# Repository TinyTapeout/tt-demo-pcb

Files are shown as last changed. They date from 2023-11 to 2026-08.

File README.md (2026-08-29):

# Tiny Tapeout Demo Board

Demo board for Tiny Tapeout ASICs

Demoboard PCB

These demonstration PCBs allow you to interact with [Tiny Tapeout](https://tinytapeout.com/) projects in 3 ways:

  * directly, using the input DIP switches and 7-segment display;
  * via breadboard or extension boards through PMODs; or
  * by interacting through the on-board RP2

Demoboard PCB

In addition, since TT06, it is possible to create analog and mixed signal designs.  These signals are now available on a 100mil header directly on the demoboard

Breakout Board Analog IO

## Pinout Overview

Demoboard Pinout

### Previous Demoboard Versions

The details above are for the latest version of the demoboard.  To access leaflets and schematics for prior versions, see [here, in the historic documentation](doc/historic/README.md)

## Schematic and Function

The full schematic is available as a [PDF](doc/tt-etr-dbv3.pdf) but the gist of it is:

Demoboard schematic

The RP2350 is responsible for selecting projects, by controlling the project MUX that's on the ASIC and, under most circumstances, providing the clock for the projects. It may, thereafter, interact with the design via it's connections to the input, output and bidirectional pins.

Another option is to use the various PMOD and pin headers to tie external circuitry to the design.  PMODs are provided in two varieties: straightforward I/O (where one PMOD is dedicated to each of in/out/bidir pins) and "standard" PMODs, that are mapped (mostly) according to specs to allow for SPI, I2C and UART extension boards to be plugged in (this assumes the project has been designed with this in mind, with I/O tasked accordingly). 

## PMODs

In addition with interfacing directly with projects via the RP2, extensions and interaction with the ASIC is possible through two sets of [PMODs](https://digilent.com/reference/_media/reference/pmod/pmod-interface-specification-1_2_0.pdf) on the demo boards.

The three on the bottom provide access to all the project I/O in a logical fashion, with inputs, bidirectional pins and outputs available on their own distinct headers.

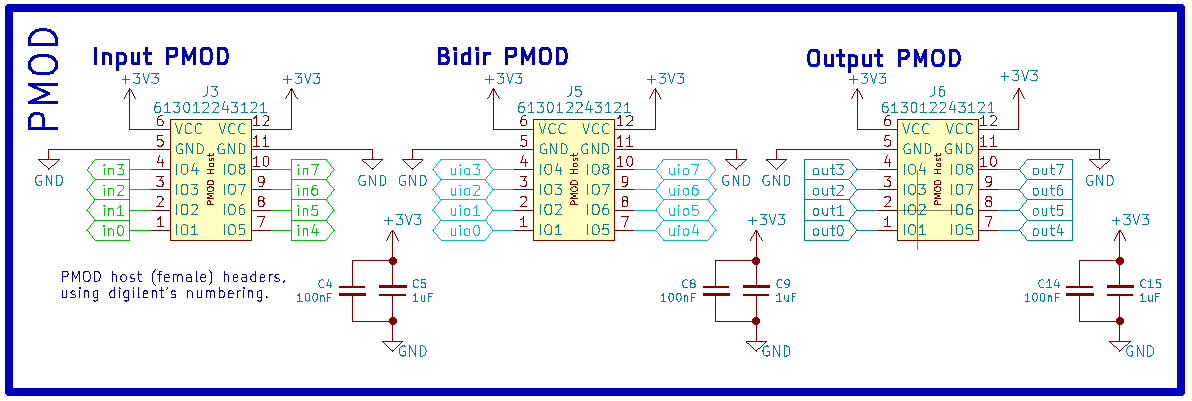
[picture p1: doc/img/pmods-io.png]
IO PMODs


This is nice and orderly and gives you access to all the pins, but extension boards will often need to span at least two, and sometimes three, distinct headers.

For interfacing peripheral modules, an interposer board was created (TODO: display and link) to provide more standard mixes of input and output on single PMODs.

## RP2 Pinout

| TT Pin | RP2 Pin | I2C | SPI | UART |
| --- | --- | --- | --- | --- |
| reset | GPIO14 | | | |
| clock | GPIO16 | | | |
| ui_in[0]  | GPIO17 | | SPI0.cs  | |
| ui_in[1]  | GPIO18 | | SPI0.sck | |
| ui_in[2]  | GPIO19 | | SPI0.tx  | |
| ui_in[3]  | GPIO20 | | | UART1.tx |
| ui_in[4]  | GPIO21 | | SPI0.cs  | |
| ui_in[5]  | GPIO22 | | SPI0.sck | |
| ui_in[6]  | GPIO23 | | SPI0.tx  | UART1.rts|
| ui_in[7]  | GPIO24 | | | |
| uio[0] | GPIO25 | I2C0.scl | SPI1.cs  | UART1.rx |
| uio[1] | GPIO26 | I2C1.sda | SPI1.sck | UART1.cts|
| uio[2] | GPIO27 | I2C1.scl | SPI1.tx  | UART0.rts|
| uio[3] | GPIO28 | I2C0.sda | SPI1.rx  | UART0.tx |
| uio[4] | GPIO29 | I2C0.scl | SPI1.cs  | UART0.rx |
| uio[5] | GPIO30 | I2C1.sda | SPI1.sck | UART0.cts|
| uio[6] | GPIO31 | I2C1.scl | SPI1.tx  | UART0.rts|
| uio[7] | GPIO32 | | | |
| uo_out[0] | GPIO33 | | | UART0.rx |
| uo_out[1] | GPIO34 | | | UART0.cts|
| uo_out[2] | GPIO35 | | | |
| uo_out[3] | GPIO36 | | SPI0.rx  | |
| uo_out[4] | GPIO37 | | | UART1.rx |
| uo_out[5] | GPIO38 | | | UART1.cts|
| uo_out[6] | GPIO39 | | | |
| uo_out[7] | GPIO40 | | SPI0.rx  | |

## Removing the ASIC breakout board

With the [Hirose DF12 Series](https://www.hirose.com/product/series/DF12) connectors now in use, removing breakouts from demoboards should be much more straightforward:

* Insert a finger on opposite diagonals (top left, bottom right)
* Gently pry upwards until the breakout pops off.

There are markings indicating where the actually connectors are placed, on the underside, on the breakouts.

## License

* The PCB is licensed under the [Apache2 License](LICENSE)
* The documentation is licensed under the [CC0](https://creativecommons.org/publicdomain/zero/1.0/)
* OSHWA registration [CA000047](https://certification.oshwa.org/ca000047.html)

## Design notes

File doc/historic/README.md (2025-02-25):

# Schematics for prior demoboard versions

Though this schematic and layout data is all preserved in the commit history, for ease of reference the major milestones are accessible here, in reverse chronological order.

These should be the revisions actually sent to production for distribution.  The PDF includes the full schematic and the preview gives access to the most important information, as the RP2040 support sheet basically doesn't change.

## TT07

With the TT07 demoboard, signal naming was uniformized (using *ui_in*, *uo_out*).

TT07 leaflet

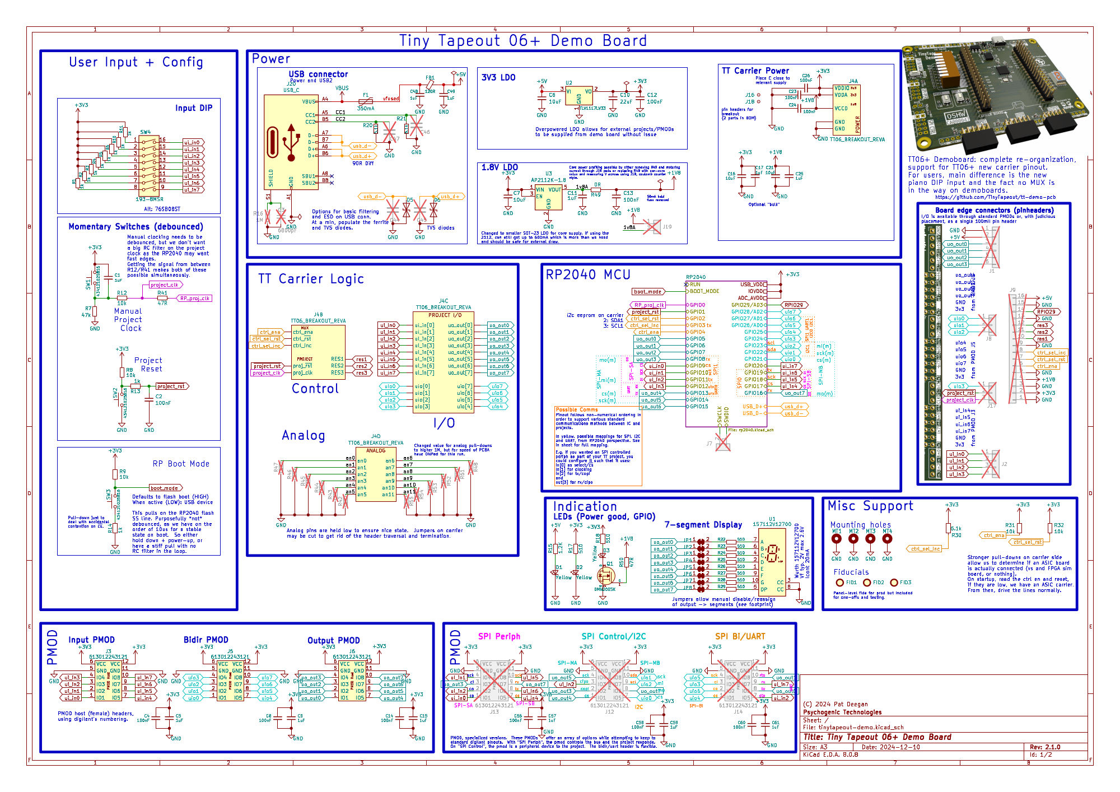
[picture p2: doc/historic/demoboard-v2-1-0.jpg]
TT07 schematic


[Version 2.1.0 schematic PDF](demoboard-v2-1-0.pdf)

Commit a799acb3886b682b0f86c2f4d6155c08b5c505de from Wed Dec 11, 2024

## TT06

With TT06, the discreet MUX was dropped (along with Caravel support), the new much more comfortable piano switches were introduced for the input port.  The carrier format changed to break compatibility with prior boards, because of a new pinout and analog pin support.

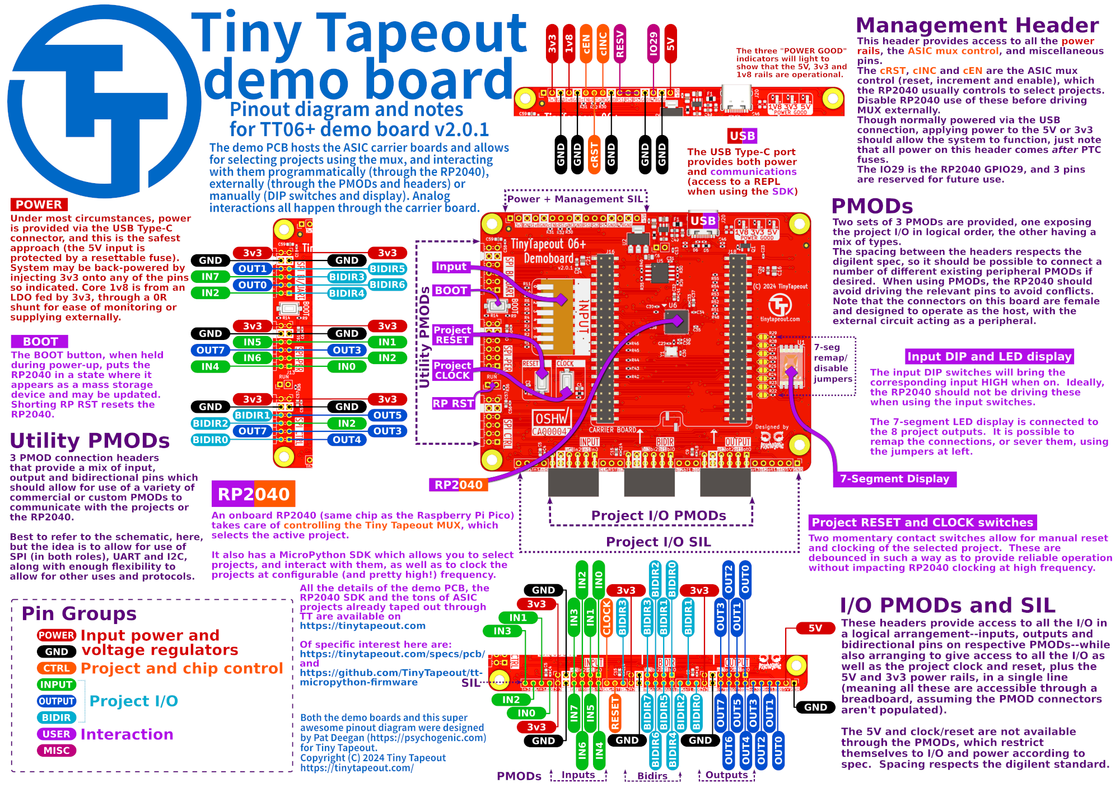
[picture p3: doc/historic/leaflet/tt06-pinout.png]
TT06 leaflet


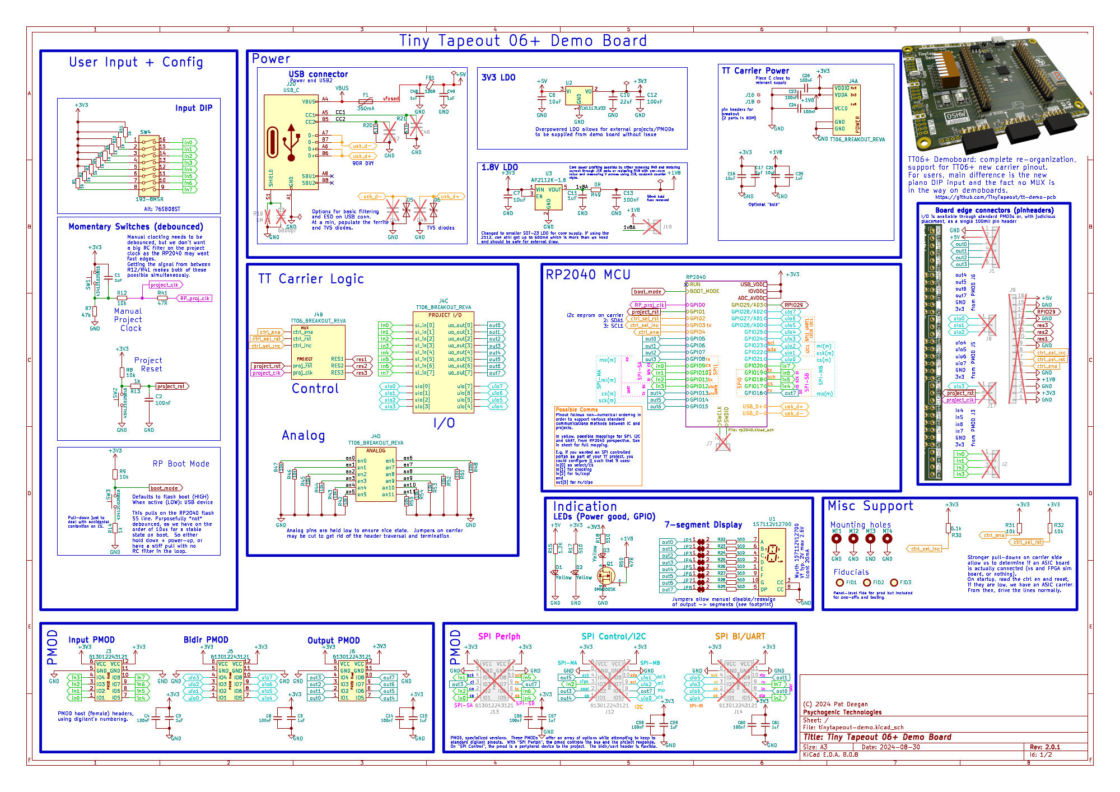
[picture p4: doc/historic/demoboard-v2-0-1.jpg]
TT06 schematic


[Version 2.0.1 schematic PDF](demoboard-v2-0-1.pdf)

Commit 292760e1f727d805be471b7700232c9482b70ae3 from Thu Oct 10, 2024

## TT05

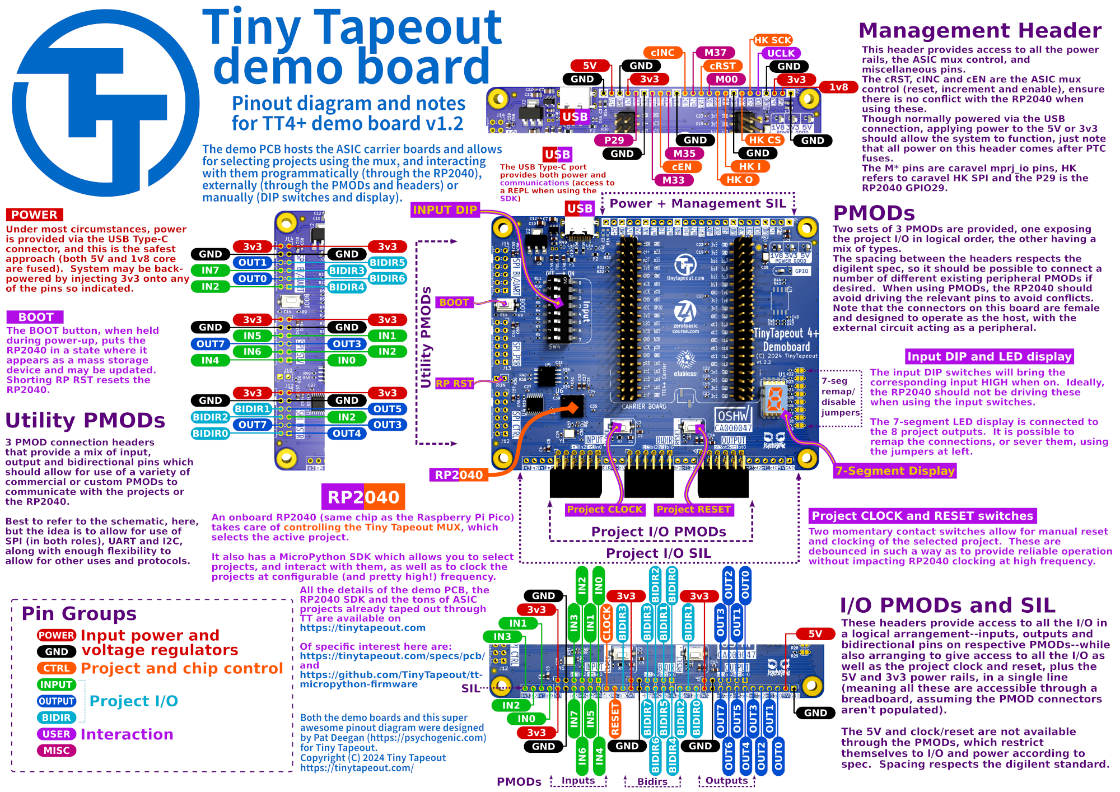
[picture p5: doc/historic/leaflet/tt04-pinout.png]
TT04/TT05 leaflet


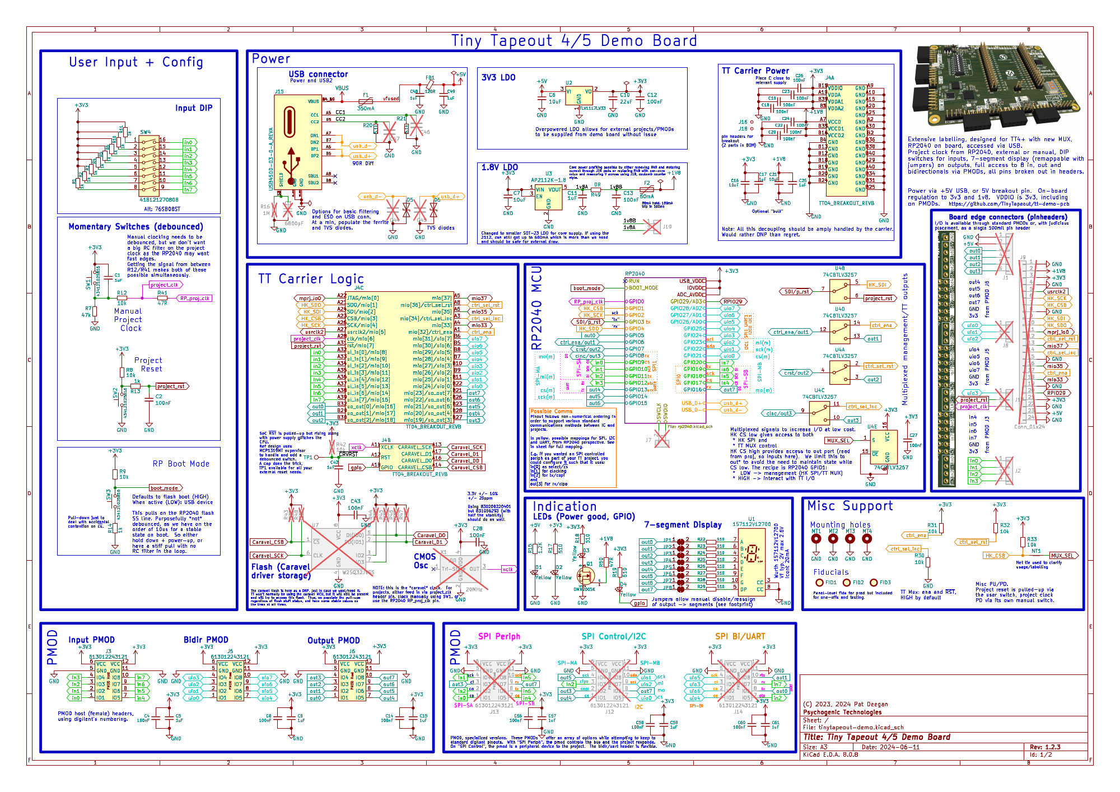
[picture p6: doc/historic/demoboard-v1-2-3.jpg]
TT05 schematic


[Version 1.2.3 schematic PDF](demoboard-v1-2-3.pdf)

Commit a88cbc08bdef564b16dc113f4489af65ff2ee86b from Tue Jun 11, 2024

## TT04

The TT04 demoboard introduced the RP2040, to handle selecting the projects through the ASIC project MUX.  TT04 boards also used a discreet multiplexer in order to provide enough pinnage to do all the things and have access to the caravel HK SPI safety net.

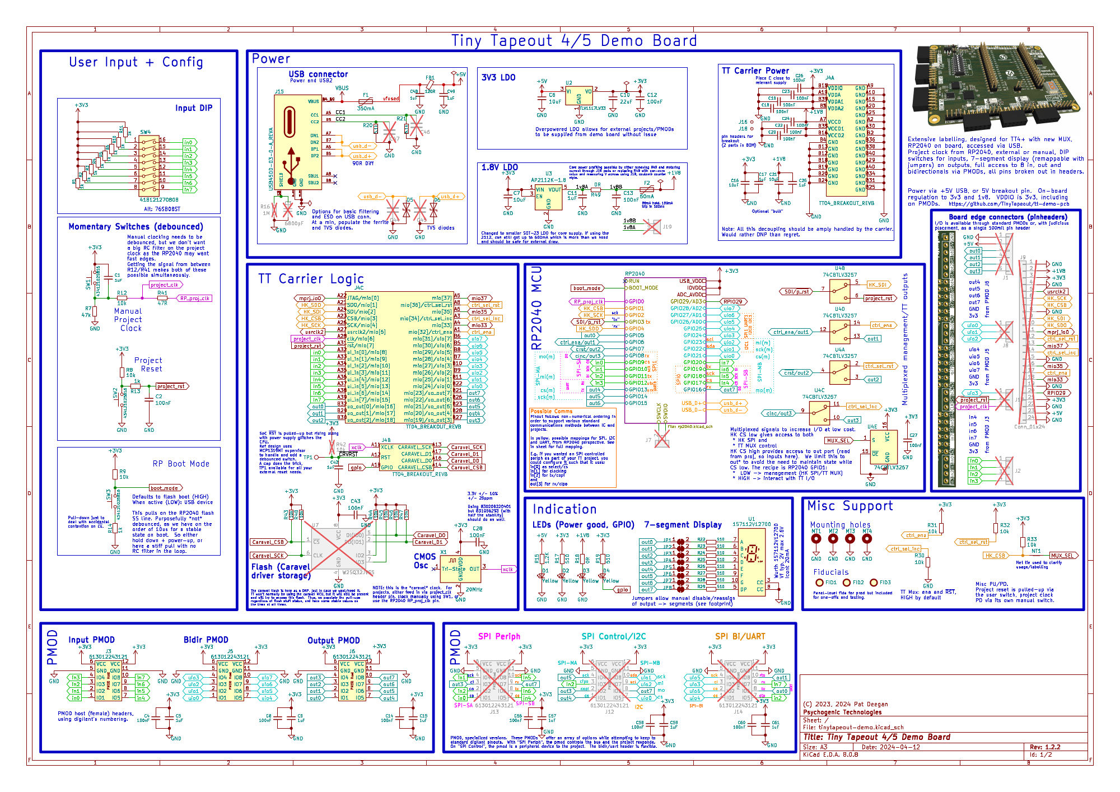
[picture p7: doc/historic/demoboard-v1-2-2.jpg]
TT04 schematic


[Version 1.2.2 schematic PDF](demoboard-v1-2-2.pdf)

Commit cfdd80d7b79a667883998caccc05ebfad5d1b985 from Fri Apr 26, 2024

## TT02/TT03

Original demoboard used with TT02 and TT03.

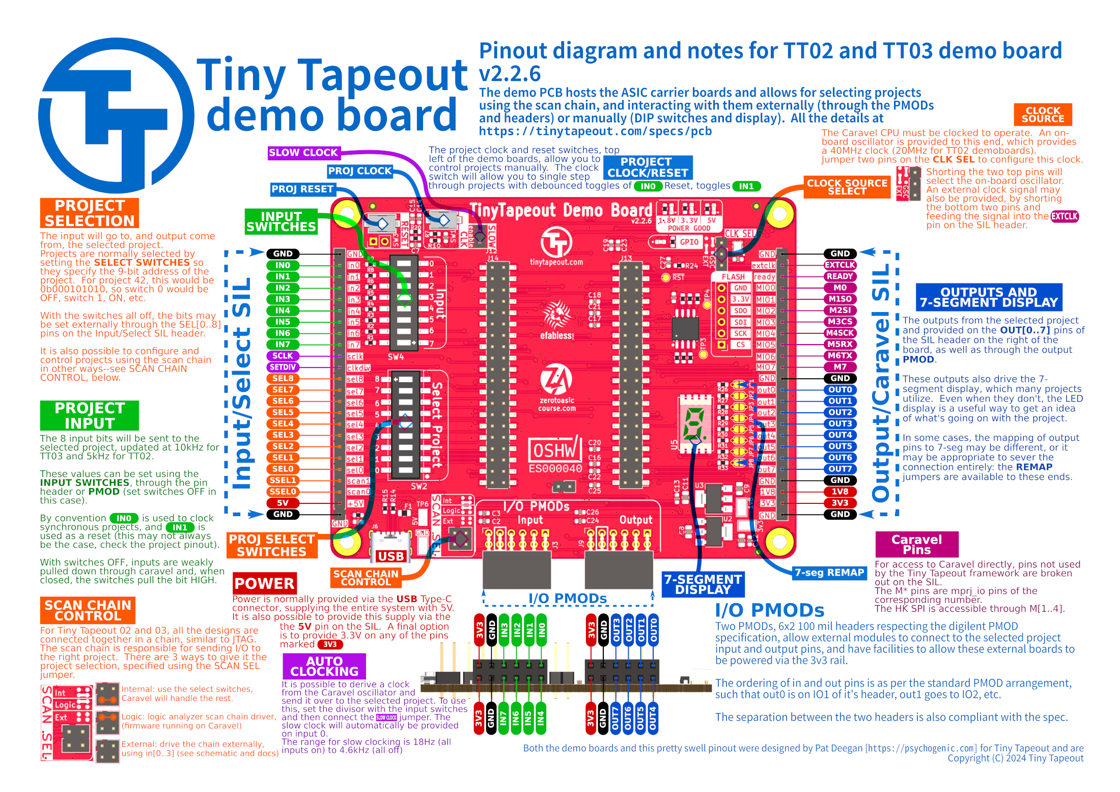
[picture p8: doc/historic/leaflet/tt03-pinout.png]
TT03 leaflet


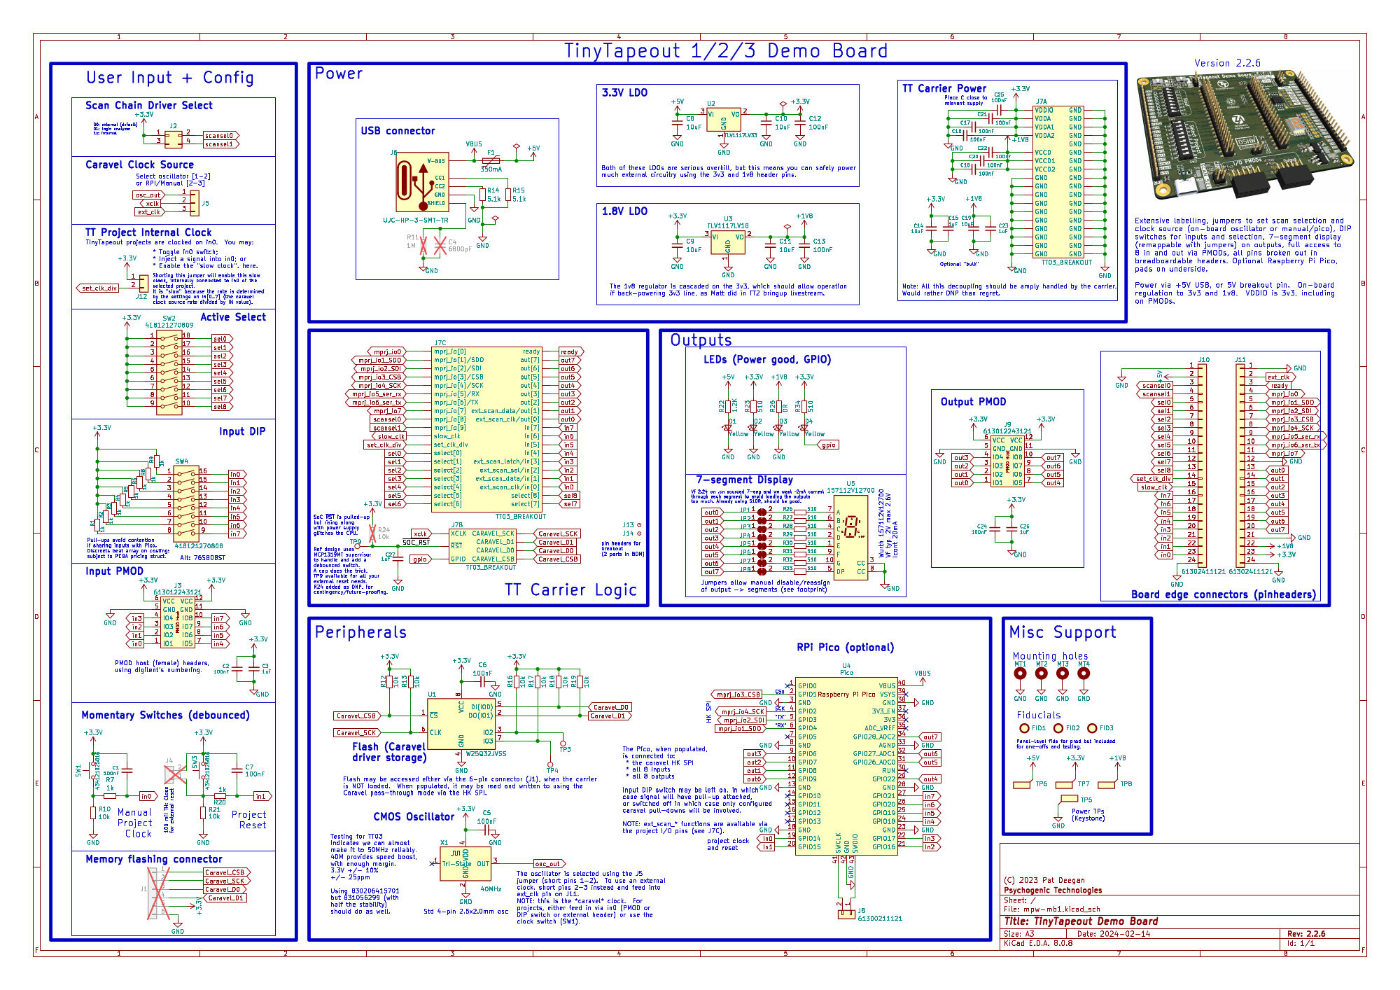
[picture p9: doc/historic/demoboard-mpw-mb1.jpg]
TT03 schematic


[TT03 demoboard schematic PDF](demoboard-mpw-mb1.pdf)

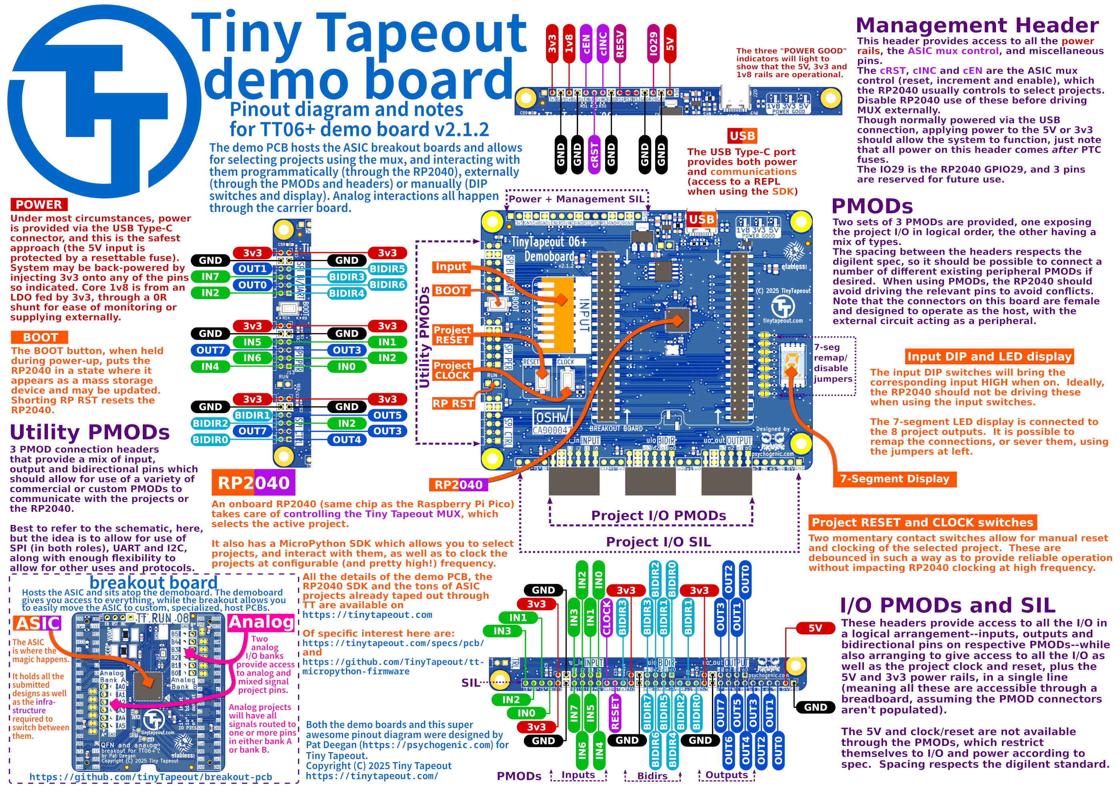
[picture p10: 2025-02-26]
doc/img/tt08-demoboard-pinout.jpg

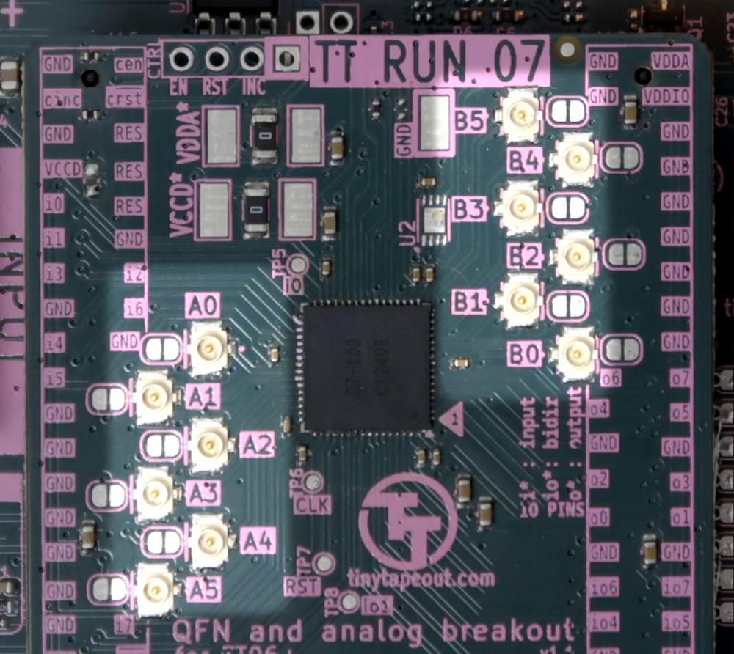
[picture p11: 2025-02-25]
doc/img/tt07-analogio.jpg

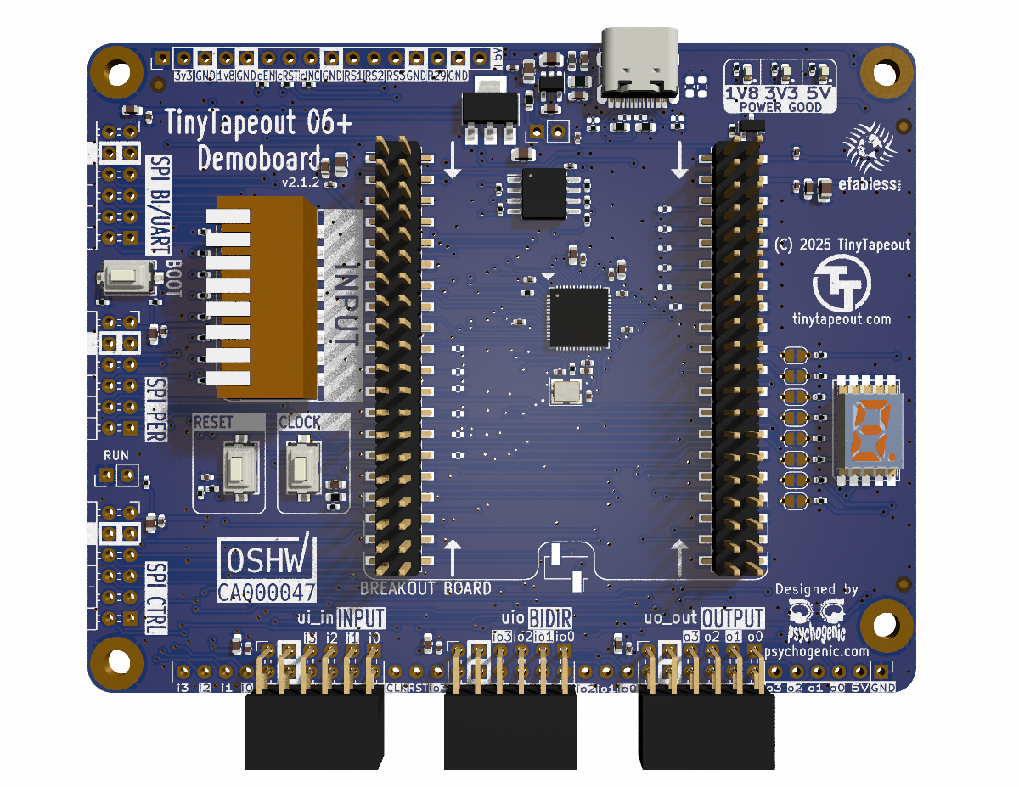
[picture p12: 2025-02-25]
doc/img/tt07-demoboard-render.jpg

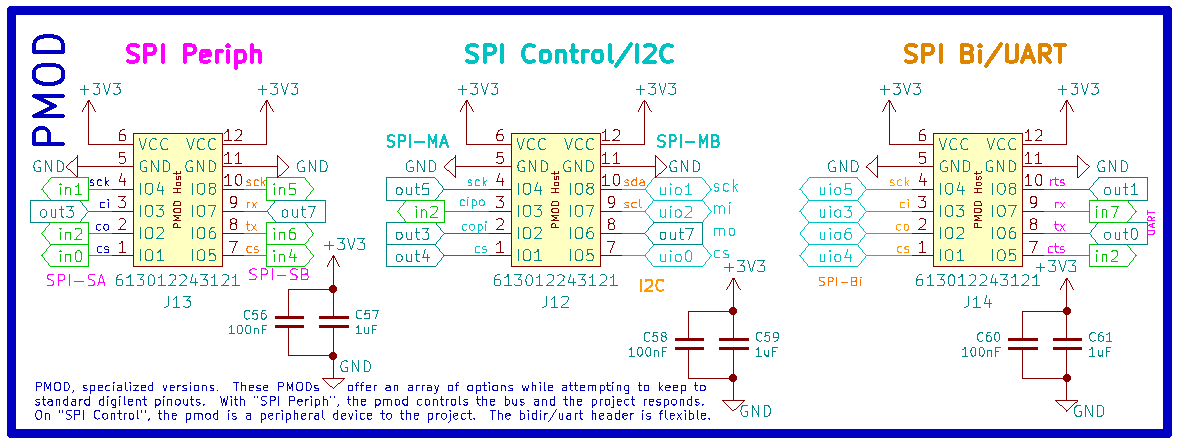
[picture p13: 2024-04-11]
doc/img/pmods-mixed.png

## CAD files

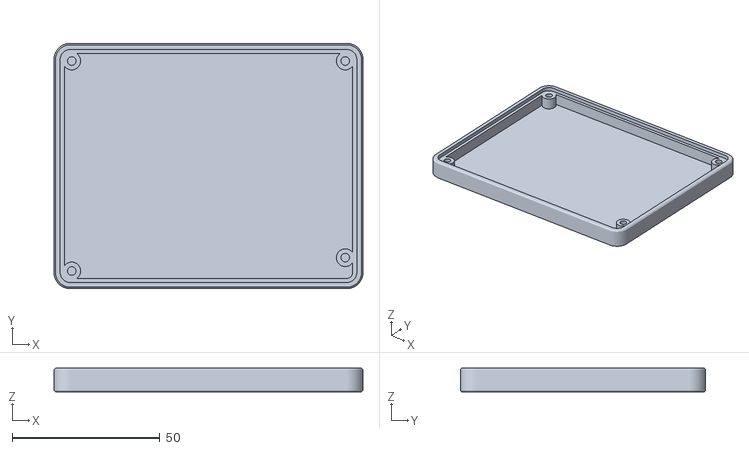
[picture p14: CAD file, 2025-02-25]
case/tt06_demo_base_m3_direct.stl
104.5 x 83.0 x 8.00

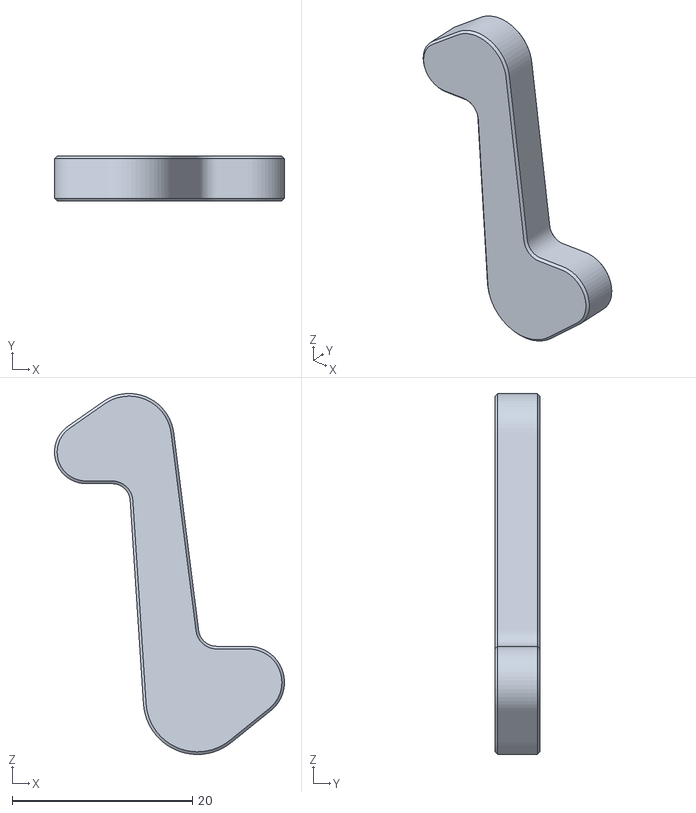
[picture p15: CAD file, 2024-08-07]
pcb_extractor.stl
25.5 x 5.00 x 40.0

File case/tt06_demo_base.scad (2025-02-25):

/* 
 * Base for Tiny Tapeout 06+ Demoboard
 *
 * Design: hxr.social/@thomasflummer
 *
 * License: CC-BY-SA
 *
 */

/*
 * Variables for Customizer
 * ==================================================================
 *
 */

// select type of mounting hardware
Screw_Type = "M2 with insert"; // [M3 direct, M2 with insert]

//-----------------
/* [AdditionalSettings] */ 

// total height (in mm)
Height = 8;

module pcb_base(width, length, pcb_thickness, corner_radius, height, mounting_hole_diameter)
{
    difference()
    {
        union()
        {
            hull()
            {
                for(x = [-1, 1])
                {
                    for(y = [-1, 1])
                    {
                        translate([x*(width/2 - corner_radius), y*(length/2 - corner_radius), height/2])
                            cylinder(r = corner_radius + 2, h = height, center = true, $fn = 150);
                    }
                }

                for(x = [-1, 1])
                {
                    for(y = [-1, 1])
                    {
                        translate([x*(width/2 - corner_radius), y*(length/2 - corner_radius), height/2])
                            cylinder(r = corner_radius + 2 + 0.5, h = height-1, center = true, $fn = 150);
                    }
                }
            }        
        }
        union()
        {
            // PCB cutout
            hull()
            {
                for(x = [-1, 1])
                {
                    for(y = [-1, 1])
                    {
                        translate([x*(width/2 - corner_radius), y*(length/2 - corner_radius), height - pcb_thickness/2])
                            cylinder(r = corner_radius + 0.4, h = pcb_thickness + 0.01, center = true, $fn = 150);
                    }
                }
            }

            // space for PTH pins and rubber feet
            hull()
            {
                for(x = [-1, 1])
                {
                    for(y = [-1, 1])
                    {
                        translate([x*(width/2 - corner_radius), y*(length/2 - corner_radius), height/2 + 1.5])
                            cylinder(r = corner_radius - 1, h = height, center = true, $fn = 150);
                    }
                }
            }
        }
    }
    // studs for screws/inserts
    
    for(x = [-1, 1])
    {
        for(y = [-1, 1])
        {
            if(x == 1 && y == -1)
            {
                difference()
                {
                    translate([x*(width/2 - 3.5), y*(length/2 - 8), (height - pcb_thickness)/2])
                        cylinder(d = 6, h = height - pcb_thickness, center = true, $fn = 150);

                    translate([x*(width/2 - 3.5), y*(length/2 - 8), (height - pcb_thickness)/2])
                        cylinder(d = mounting_hole_diameter, h = height - pcb_thickness + 0.01, center = true, $fn = 150);
                }
            }
            else
            {
                difference()
                {
                    translate([x*(width/2 - 3.5), y*(length/2 - 3.5), (height - pcb_thickness)/2])
                        cylinder(d = 6, h = height - pcb_thickness, center = true, $fn = 150);

                    translate([x*(width/2 - 3.5), y*(length/2 - 3.5), (height - pcb_thickness)/2])
                        cylinder(d = mounting_hole_diameter, h = height - pcb_thickness + 0.01, center = true, $fn = 150);
                }
            }
        }
    }

    
}


if(Screw_Type == "M2 with insert")
{
    pcb_base(99.5, 78, 1.6, 3.0, Height, 3.3);
}

if(Screw_Type == "M3 direct")
{
    pcb_base(99.5, 78, 1.6, 3.0, Height, 2.9);
}

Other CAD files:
case/tt06_demo_base_m2_insert.stl

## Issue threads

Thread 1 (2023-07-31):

Proposed RP2040 pinout

MichaelBell, 2023-07-31:
It would be good to define which RP2040 IOs were connected to which TT user project IOs before TT04 submissions close, so that TT04 projects can know which pins to interface with RP2040 peripherals on (e.g. SPI, UART, I2C and to a lesser extent, PIO).

My proposal for the pinout would be:
```
0   TT <- RP        Input 0
1   TT <- RP        Input 1
2   TT <- RP        Input 2
3   TT <- RP        Input 3
4   TT <- RP        Input 4
5   TT <- RP        Input 5
6   TT <- RP        Input 6
7   TT <- RP        Input 7
8   TT <-> RP       Bidi 0
9   TT <-> RP       Bidi 1
10  TT <-> RP       Bidi 2
11  TT <-> RP       Bidi 3
12  TT <-> RP       Bidi 4
13  TT <-> RP       Bidi 5
14  TT <-> RP       Bidi 6
15  TT <-> RP       Bidi 7
16  TT  -> RP       Output 0
17  TT  -> RP       Output 1
18  TT  -> RP       Output 2
19  TT  -> RP       Output 3
20  TT  -> RP       Output 4
21  TT  -> RP       Output 5
22  TT  -> RP       Output 6
23  TT  -> RP       Output 7
24  Clock Output    CLK
25  Reset           RST_N
26  Controller      SEL_RST_N
27  Controller      SEL_INC
28  Controller      ENA
29  Other           LED
```

Considerations:
- For PIO, useful to be able to use contiguous blocks of pins on RP2040, so arrange the user project IOs contiguously in some order, and have the bidi IOs between the fixed direction IOs so you have the possibility of 16 contiguous inputs or outputs.
- For SPI, SPI0 is available on GPIOs 0-7, 16-23.  SPI1 is available on GPIOs 8-15, 24-29 so with this ordering both can be used (SPI0 through the fixed direction IOs, SPI1 through the bidirectional IOs).
- The UART and I2C repeat in blocks of 8 and 4 respectively, so aligning with those boundaries is sensible
- GPIOs 26-29 should not have voltage applied when the RP2040 is unpowered.  If the board has an option not to power the RP2040 these could be protected with diodes and any added delay/switching frequency concerns should not matter as those signals are not connected to the user project.

urish, 2023-10-13:
Closing as this was discussed on discord

Closed 2023-10-13.

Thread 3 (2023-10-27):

Manual clock 1-step function RC network design area review request

dlmiles, 2023-10-27:
Please review the use of R7/R12/C1 around the manual clock 1-step function.

The concern is in relation to the impact of RC circuit on the signal integrity of the `project_clk` line which is an important aspect to many projects.  Especially as the clock rate is increased through the MHz, towards 50MHz planned max RP2040 and 66MHz the documented max sky130 IO input rate (which maybe should be the PCB design limit, if someone attaches their own clock source while the RP2040 pin is tri-state/HiZ).

In particular it would be ideal validate and measure (possibly with a breadboard setup) how the signal changes at a variety of clock frequencies.  Also the shape of the signal from the button use.

Maybe a reduction of C1 (100nF) to a smaller value turns out to meet requirements ?

Other thoughts in the area:
 * consideration to using GPIO29 (if unused) to connect the clock 1-step switch to this GPIO only, make project_clk driven only by the RP2040 firmware and the removal of any extra capacitance on the project_clk net.  This might have other benefits, a button able to communicate with RP2040 firmware directly opens up other project possibilities?
 * if GPIO29 is possible, potential to leave unpopulated option in PCB design to `relink` manual clock switch back to project_clk (with the customer using a 1x2 header pin + jumper) where the track near R12 was disconnected.
 * is an RC debounce approach enough to provide intended project reliability to students for edge triggered flopflops, some people might consider a schmitt-trigger to provide output to project_clk line from a switch+RC to be the minimum approach

Related discord discussion area links:
https://discord.com/channels/1009193568256135208/1009395924017086475/1167335321365651496
https://discord.com/channels/1009193568256135208/1011201396659474432/1167393079456714783

mattvenn, 2024-03-01:
resolved

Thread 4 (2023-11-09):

caravel reset missing?

mattvenn, 2023-11-09:
I see project reset and project select reset, but not caravel reset. This needs properly taking care of or we will have the same issue for the v2.2.3 tt123 demo boards.

Closed 2024-03-01.

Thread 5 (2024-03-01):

minor fixes

mattvenn, 2024-03-01:
fix copyright on pdf schematic

add license to repo

typo: periphas -> "periph as" on the pdf schematic

readme:

TinyTapeout -> Tiny Tapeout (as per branding guideline on the www)

Add ref to license.

follow oshwa guidelines for SPI port names https://www.oshwa.org/a-resolution-to-redefine-spi-signal-names/

Closed 2024-06-11.

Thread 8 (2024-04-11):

Remove reliance on IO pull-downs

psychogenic, 2024-04-11:
We have, to date, been relying on pull-downs from Caravel.  This won't be possible for TT06 so, assuming we keep the DIP switches on the input, need to organize things differently.

Closed 2025-02-27.

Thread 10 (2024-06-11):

fix 1.8v power led brightness

mattvenn, 2024-06-11:
use a mosfet to drive the led

psychogenic, 2024-06-11:
Done, added a FET and feeding from 3v3.  Series term on gate using value we already have on the board.  Have a range of options on the specific nfet, set the LCSC number to C2891732 (basically an si2302 dirt cheap type deal).
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

Closed 2024-06-11.

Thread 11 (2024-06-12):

current measure header and 1.8 override

mattvenn, 2024-06-12:
The current method of measuring core current is to remove resistor and place a header. I would like the header to be replaced with a standard 2.54 mm pitch.

Also I would like an easy way to provide 1.8 from another source. Perhaps adding an additional gnd hole so that once the resistor is removed a 3 pin header can be placed ?

psychogenic, 2024-06-13:
Ok, replaced header with 100mil version and moved things around (blue arrow).  If you want to power with your own 1v8, remove that same R49 (blue slash) and power through headers indicated in red.  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

mattvenn, 2024-06-13:
Thanks!

Closed 2024-06-13.

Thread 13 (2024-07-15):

removing carrier board with the top header soldered is hard

mattvenn, 2024-07-15:
can't get my levers in there when the top header is soldered (the one next to usb)
if the carrier board was moved to be more central in the demo board, it would be easier to remove it by using levers

mattvenn, 2024-12-11:
with the latest configuration of components it's even harder to get the levers in

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

psychogenic, 2024-12-11:
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
The arrows are meant to indicate where to stick in your level sticks.

mattvenn, 2024-12-11:
I'm trying to say that it needs levering from the top side as well,
otherwise the pins still get bend

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

--
Matthew Venn
 Making chip design more accessible
https://www.linkedin.com/in/matt-venn/
<https://www.linkedin.com/in/matt-venn/>

psychogenic, 2024-12-11:
I have to 3D print some of your thingies, I'd thought you could inch along but they must be too short.

mattvenn, 2024-12-11:
I can get them under, but then they normally are pushing against a component instead of the board. Maybe this is actually fine, I'm just worried about popping off a component or cracking a cap

psychogenic, 2024-12-11:
It's not ideal.  Best thing might be to make the carriers a bit wider so you have a lip to use from the outside.

Closed 2025-02-27.

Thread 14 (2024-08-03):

1v8 and 3v3 on the top SIL are too easy to short if you are not careful

urish, 2024-08-03:
All it takes is one alligator clip slipping a bit and poof!

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

Let's separate them with a GND pin, to reduce the chance of other people repeating my mistake...

Closed 2025-02-27.

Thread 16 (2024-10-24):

Disable RP2040 microcontroller

InputBlackBoxOutput, 2024-10-24:
I cannot find a way to disable RP2040 to use only the PMOD connectors with the clk and reset buttons on the board

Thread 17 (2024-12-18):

efabless logo is missing on the devkits

mattvenn, 2024-12-18:
needs to be visible on the front of the board somewhere

psychogenic, 2024-12-18:
We holding '07 for this, or good for the next run?

psychogenic, 2024-12-18:
All right.  Don't think there'll be much else to change for TT08, so will do shortly.

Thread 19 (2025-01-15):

uio[6] appear to be shorted to the 3.3v rail

proppy, 2025-01-15:
Board: TinyTapeout 4+ Demo Board `OSHWCA000047`

I noticed that uio[6] was always pulled up and when testing w/ a contact tester and  the board unplugged and it appear that it is statically connected to the 3.3v pins of the Project I/O PMODs.

Any ideas to troubleshoot further?

mattvenn, 2025-02-27:
Did you resolve this?

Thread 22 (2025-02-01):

Components interfere with levering out the breakout board: make space somehow

psychogenic, 2025-02-01:
U2, the flash, and the lack of clarity on where to stick the 3-printed levers when removing the breakout.  Try and make some space and indicate the path better than the small arrows in use now:

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

mattvenn, 2025-02-01:
Have you tried the levers? They work much better at the top and bottom of
the breakout, not both at the bottom (where they cause pin bendage at the
top)

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

MichaelBell, 2025-02-01:
As Matt notes, the bottom side is no problem.  A similar clear path on the top side is also needed to lift the carrier off evenly without risking pin bendage.

With the current design you can just about get one tool in behind the USB port on the top side, but it's a bit fiddly and seems non-zero risk to the port and the diodes beneath the port.

psychogenic, 2025-02-11:
Wanted to keep the bigger regulator and not disrupt things too badly, wound up with this.
I finally printed out the levers and they don't need to go too deep to function, we basically just need access to the four corners, which this should allow without too much issue
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

mattvenn, 2025-02-12:
apart from adding the arrow, it looks no different to my TT06 board - what changed?
for me when I try to put in the levers at the top, on the right the usb socket gets in the way, and on the left the regulator gets in the way

psychogenic, 2025-02-12:
> apart from adding the arrow, it looks no different to my TT06 board

Well I never!1!

It's the most I could do without moving a ton of wiring, but still got a couple of mm clearance--heat map of changes below.

The fact is, though, I can send a video of how I've been doing it with current boards: if you come in "on the side" and twist it works, and then you only have an issue when your lever is down touching the PCB, which this I think is enough to change.

Also, with 60% infill we could prob make the things thinner without issue.

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

mattvenn, 2025-02-12:
good point on the width, they probably can be thinner

Closed 2025-02-27.

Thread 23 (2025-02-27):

Kicad ERC should run with no warnings / errors

mattvenn, 2025-02-27:

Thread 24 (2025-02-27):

Kicad DRC should run with no warnings or errors

mattvenn, 2025-02-27:

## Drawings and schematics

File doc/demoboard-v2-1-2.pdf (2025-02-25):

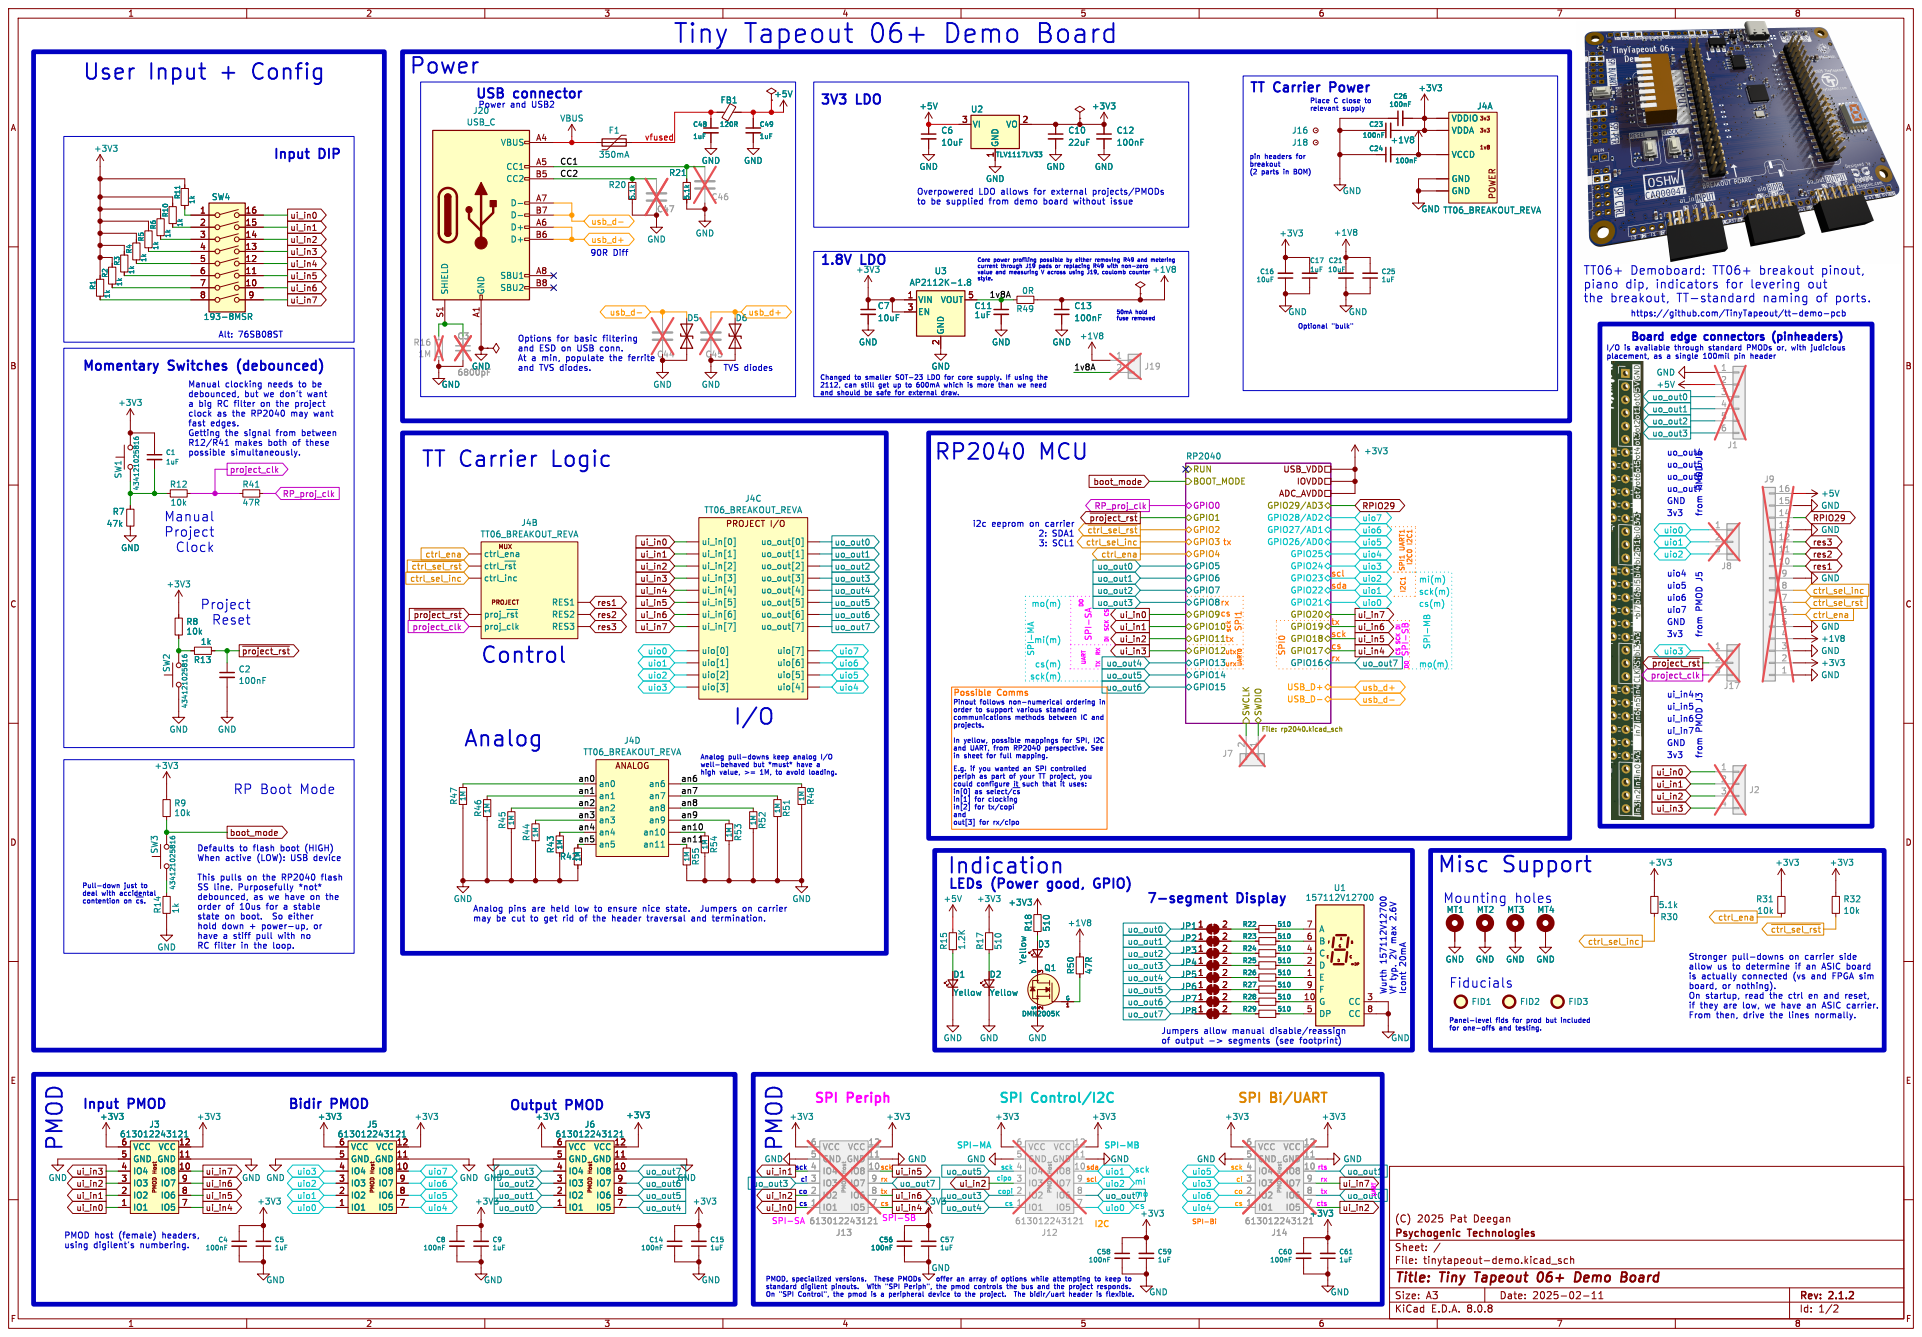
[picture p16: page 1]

tx Tiny Tapeout 06+ Demo Board

pin headers for breakout (2 parts in BOM)

2 EN 3 VOUT 5 GND GND GND GND

2112, can still get up to 600mA which is more than we need

tx TT Carrier Logic

mo(m) E.g. if you wanted an SPI controlled

in sheet for full mapping.

order of 10us for a stable

rts SPI Bi/UART

Id: 1/2 Title: Tiny Tapeout 06+ Demo Board

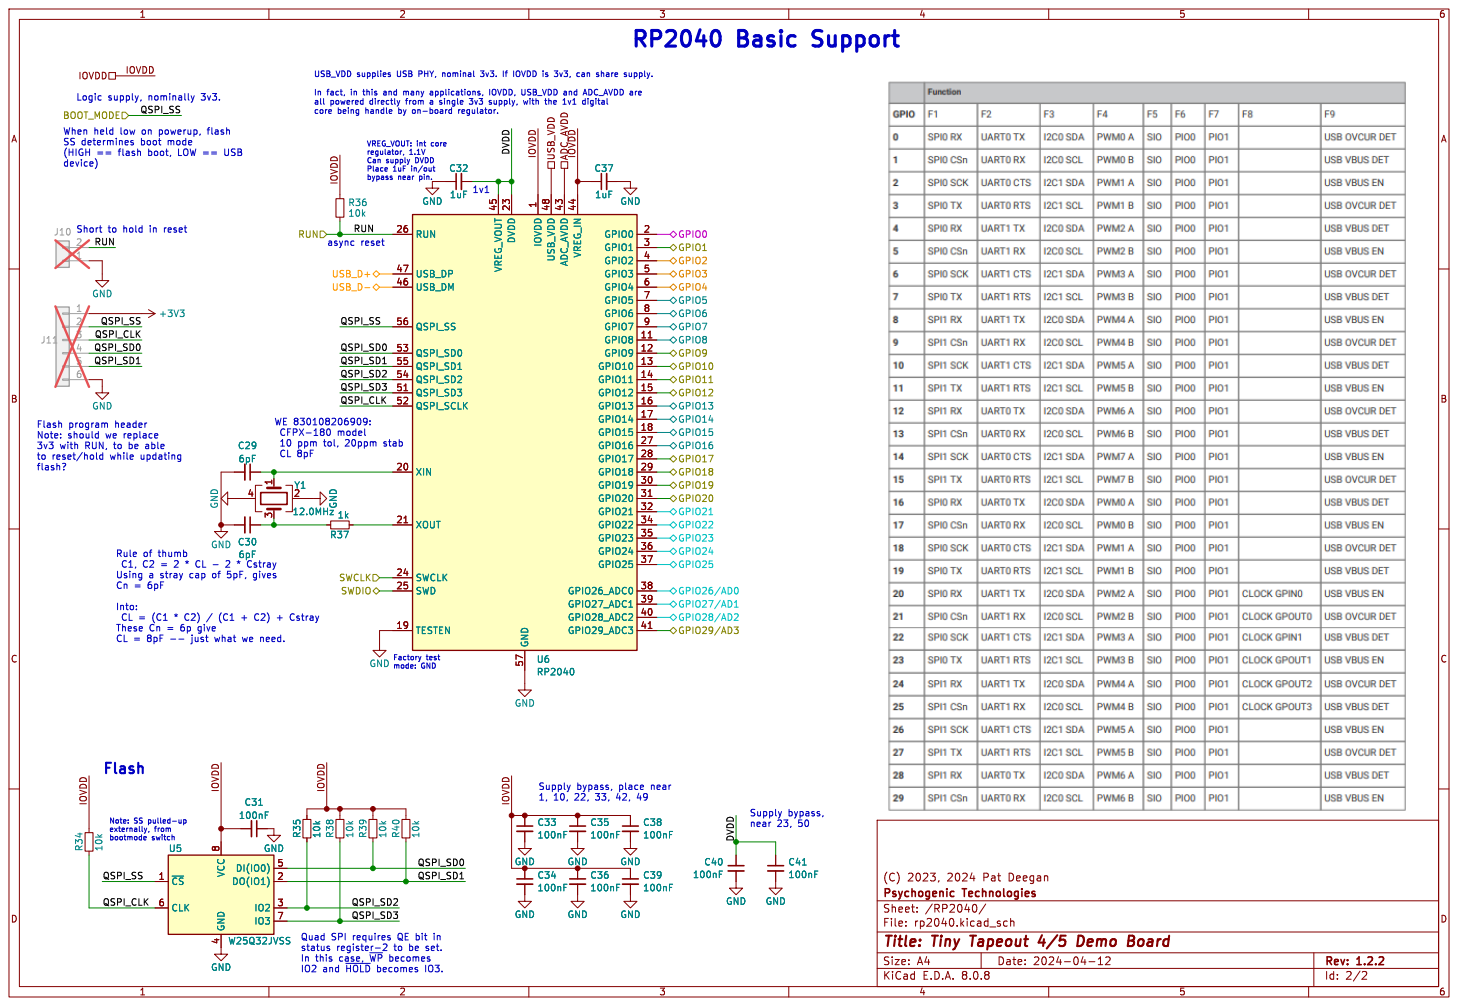
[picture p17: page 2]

async reset Quad SPI requires QE bit in

(HIGH == flash boot, LOW == USB
device)

1 GPIO8 11 GPIO9 12 GPIO10 13 GPIO11 14 GPIO12 15 GPIO13 16 GPIO14 17 GPIO15 18 TESTEN 19 GPIO0 2 XIN 20 XOUT 21 DVDD 23 SWCLK 24 SWD 25 RUN 26 GPIO16 27 GPIO17 28 GPIO18 29 GPIO1 3 GPIO19 30 GPIO20 31 GPIO21 32 GPIO22 34 GPIO23 35 GPIO24 36 GPIO25 37 GPIO26_ADC0 38 GPIO27_ADC1 39 GPIO2 4 GPIO28_ADC2 40 GPIO29_ADC3 41 ADC_AVDD 43 VREG_IN 44 VREG_VOUT 45 USB_DM 46 USB_DP 47 USB_VDD 48 GPIO3 5 QSPI_SD3 51 QSPI_SCLK 52 QSPI_SD0 53 QSPI_SD2 54 QSPI_SD1 55 QSPI_SS 56 GND 57 GPIO4 6 GPIO5 7 GPIO6 8 GPIO7 9 GND GND

1 GPIO8 11 GPIO9 12 GPIO10 13 GPIO11 14 GPIO12 15 GPIO13 16 GPIO14 17 GPIO15 18 TESTEN 19 GPIO0 2 XIN 20 XOUT 21 DVDD 23 SWCLK 24 SWD 25 RUN 26 GPIO16 27 GPIO17 28 GPIO18 29 GPIO1 3 GPIO19 30 GPIO20 31 GPIO21 32 GPIO22 34 GPIO23 35 GPIO24 36 GPIO25 37 GPIO26_ADC0 38 GPIO27_ADC1 39 GPIO2 4 GPIO28_ADC2 40 GPIO29_ADC3 41 ADC_AVDD 43 VREG_IN 44 VREG_VOUT 45 USB_DM 46 USB_DP 47 USB_VDD 48 GPIO3 5 QSPI_SD3 51 QSPI_SCLK 52 QSPI_SD0 53 QSPI_SD2 54 QSPI_SD1 55 QSPI_SS 56 GND 57 GPIO4 6 GPIO5 7 GPIO6 8 GPIO7 9 U6 RP2040 ~{CS} 1 DO(IO1) 2

Flash program header Note: should we replace

3v3 with RUN, to be able
flash?

Using a stray cap of 5pF, gives Cn = 6pF

Factory test mode: GND

Note: SS pulled-up

In this case, ~{WP}becomes
IO2 and ~{HOLD}becomes IO3.

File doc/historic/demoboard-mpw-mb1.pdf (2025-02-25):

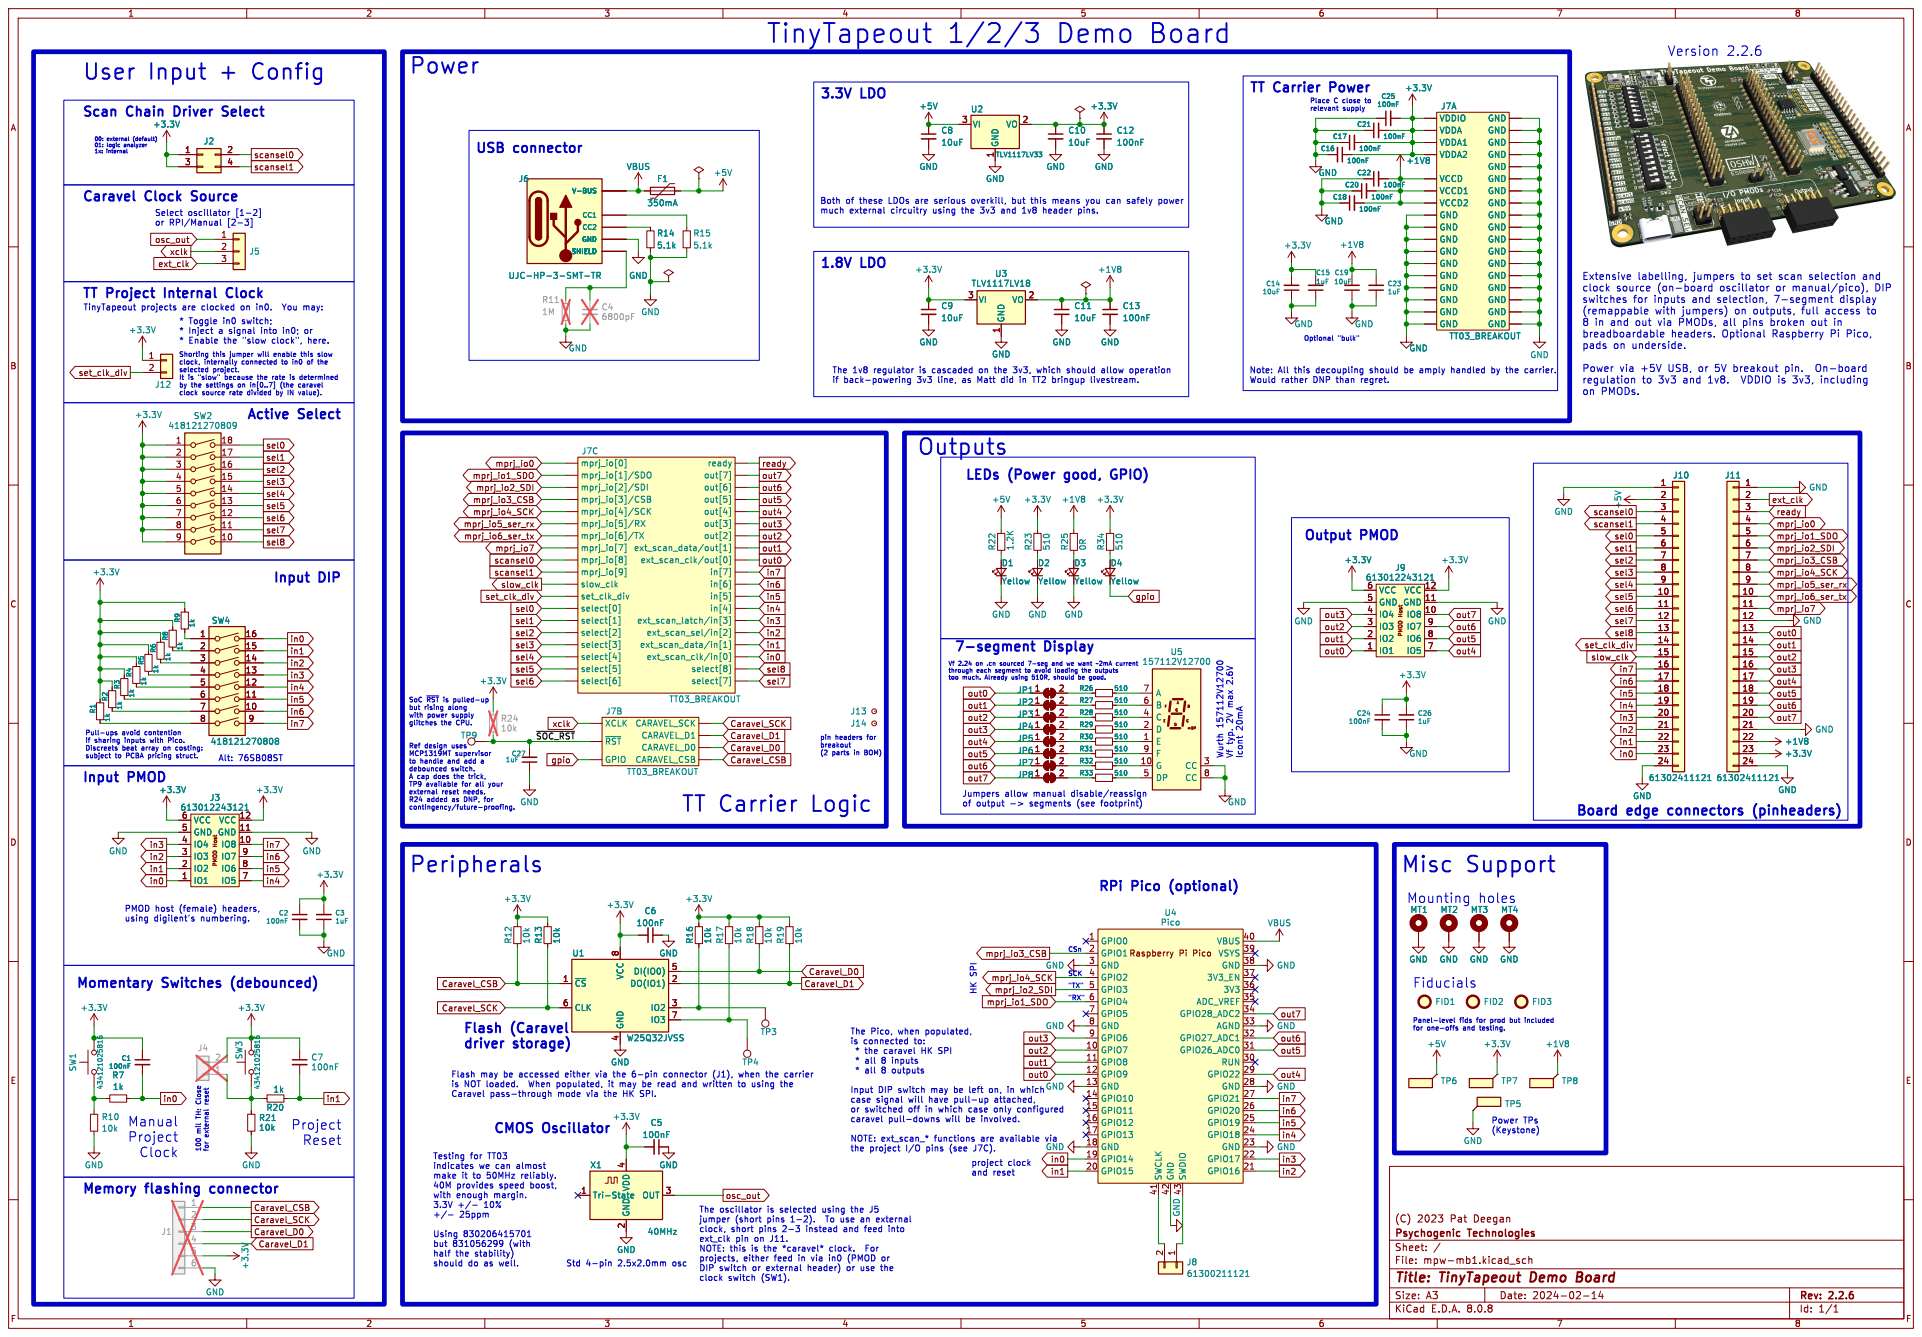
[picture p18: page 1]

Scan Chain Driver Select

USB connector
J6 UJC-HP-3-SMT-TRGND
CC1 V-BUS CC2 SHIELD

J6 UJC-HP-3-SMT-TR

GND GND GND GND GND

8 in and out via PMODs, all pins broken out in

LEDs (Power good, GPIO)

too much. Already using 510R, should be good. pin headers for breakout (2 parts in BOM) SoC ~{RST}is pulled-up

to handle and add a

Input DIP switch may be left on, in which

Id: 1/1 Title: TinyTapeout Demo Board

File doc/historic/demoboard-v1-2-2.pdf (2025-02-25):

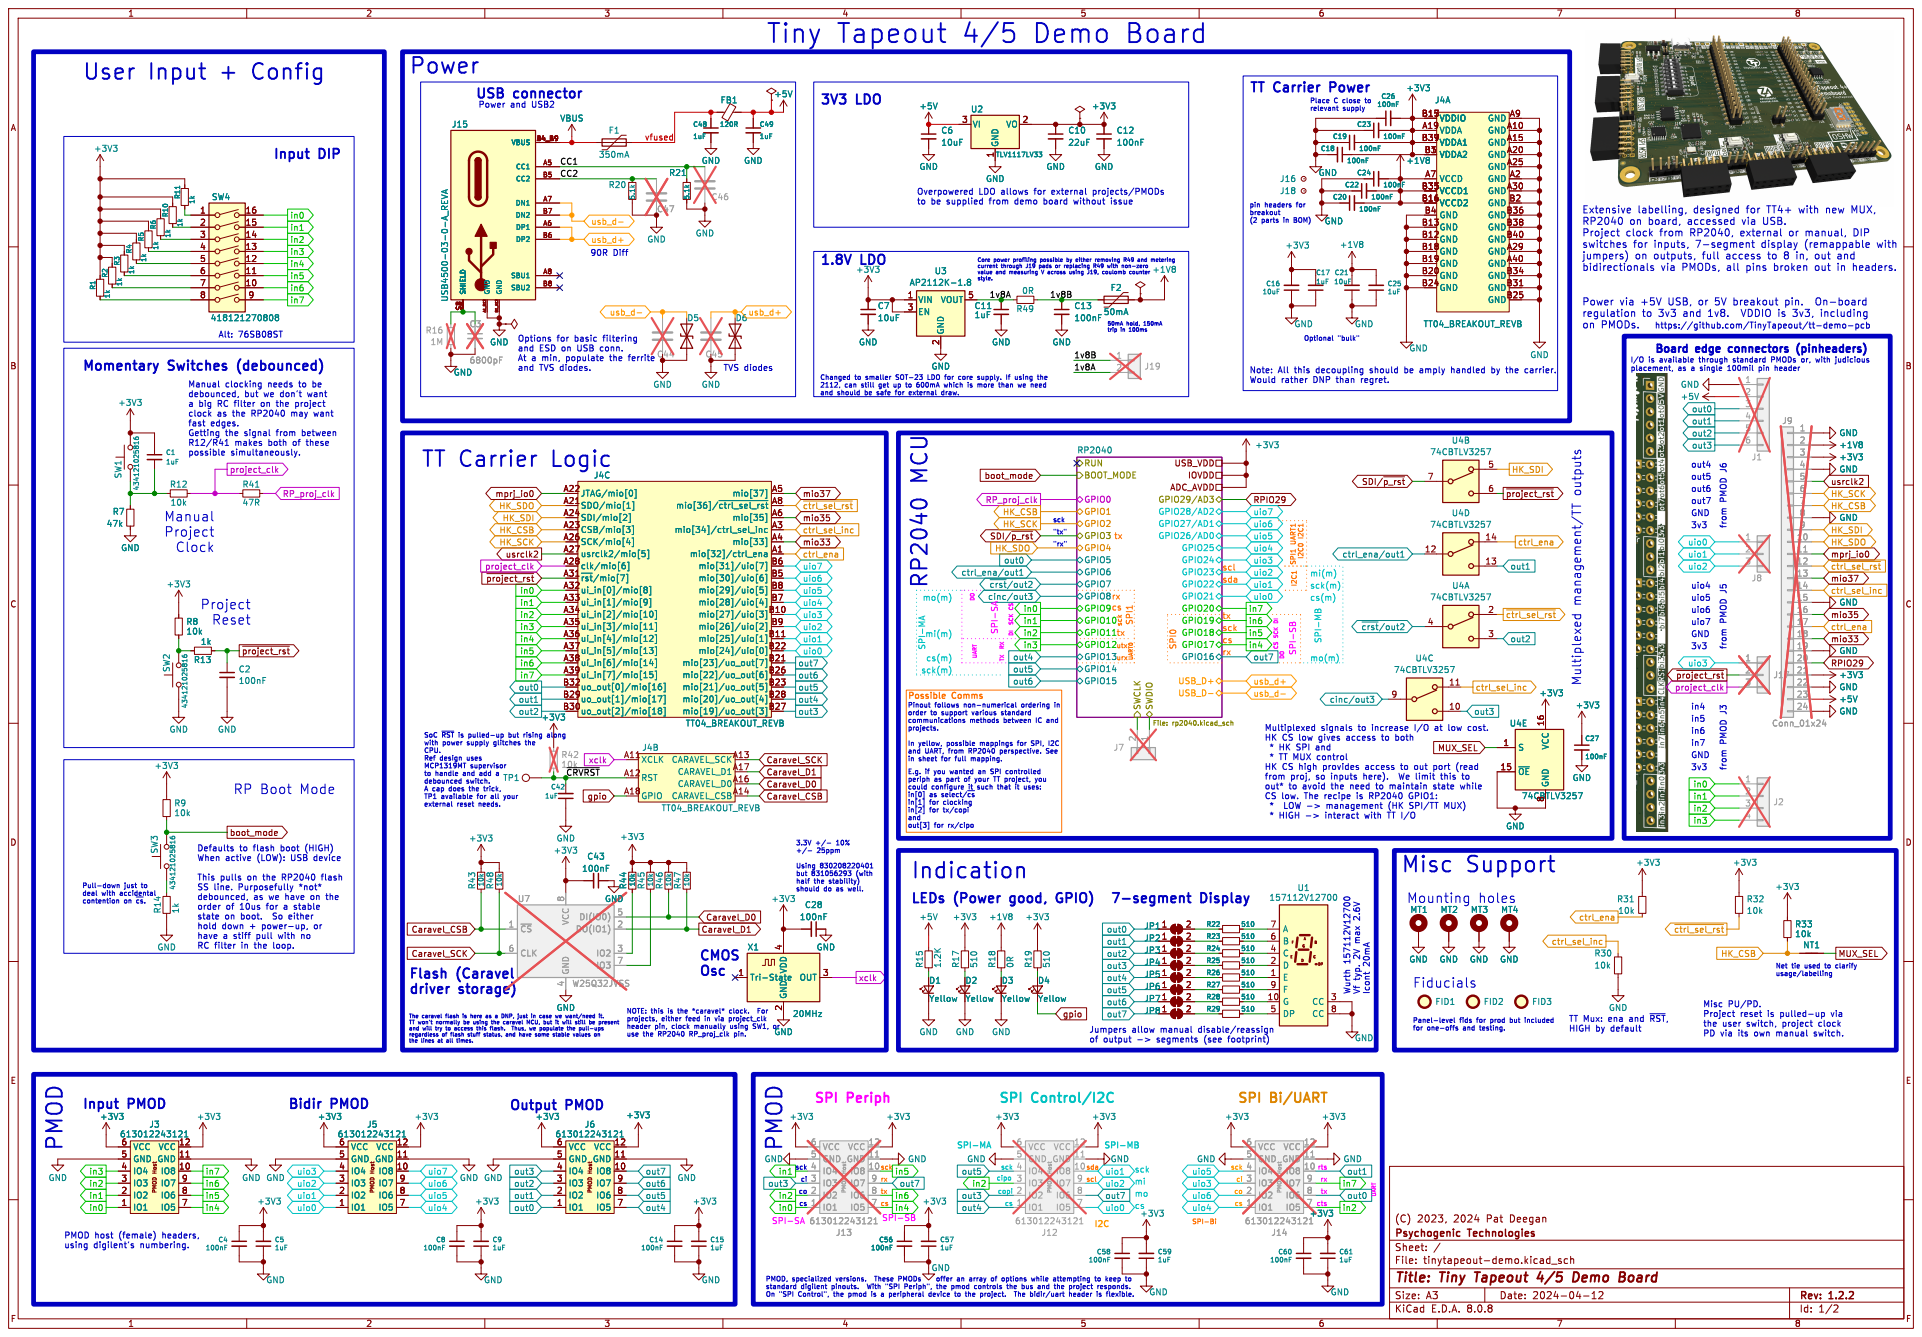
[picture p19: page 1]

scl Tiny Tapeout 4/5 Demo Board
and TVS diodes. USB connector

pin headers for breakout (2 parts in BOM)

90R Diff TT Carrier Logic

https://github.com/TinyTapeout/tt-demo-pcb from PMOD J5

usb_d+
in sheet for full mapping. RP2040 MCU

trip in 100ms Possible Comms

Options for basic filtering

2112, can still get up to 600mA which is more than we need

JTAG/mio[0] A22 CSB/mio[3] A23 SDI/mio[2] A24 SCK/mio[4] A26

GND RP Boot Mode

* HK SPI and
* TT MUX control HK CS high provides access to out port (read

to handle and add a

E.g. if you wanted an SPI controlled

half the stability) should do as well. CMOS

LEDs (Power good, GPIO)

order of 10us for a stable

the user switch, project clock PD via its own manual switch. Wurth 157112V12700 Vf typ. 2V max 2.6V Icont 20mA

Jumpers allow manual disable/reassign

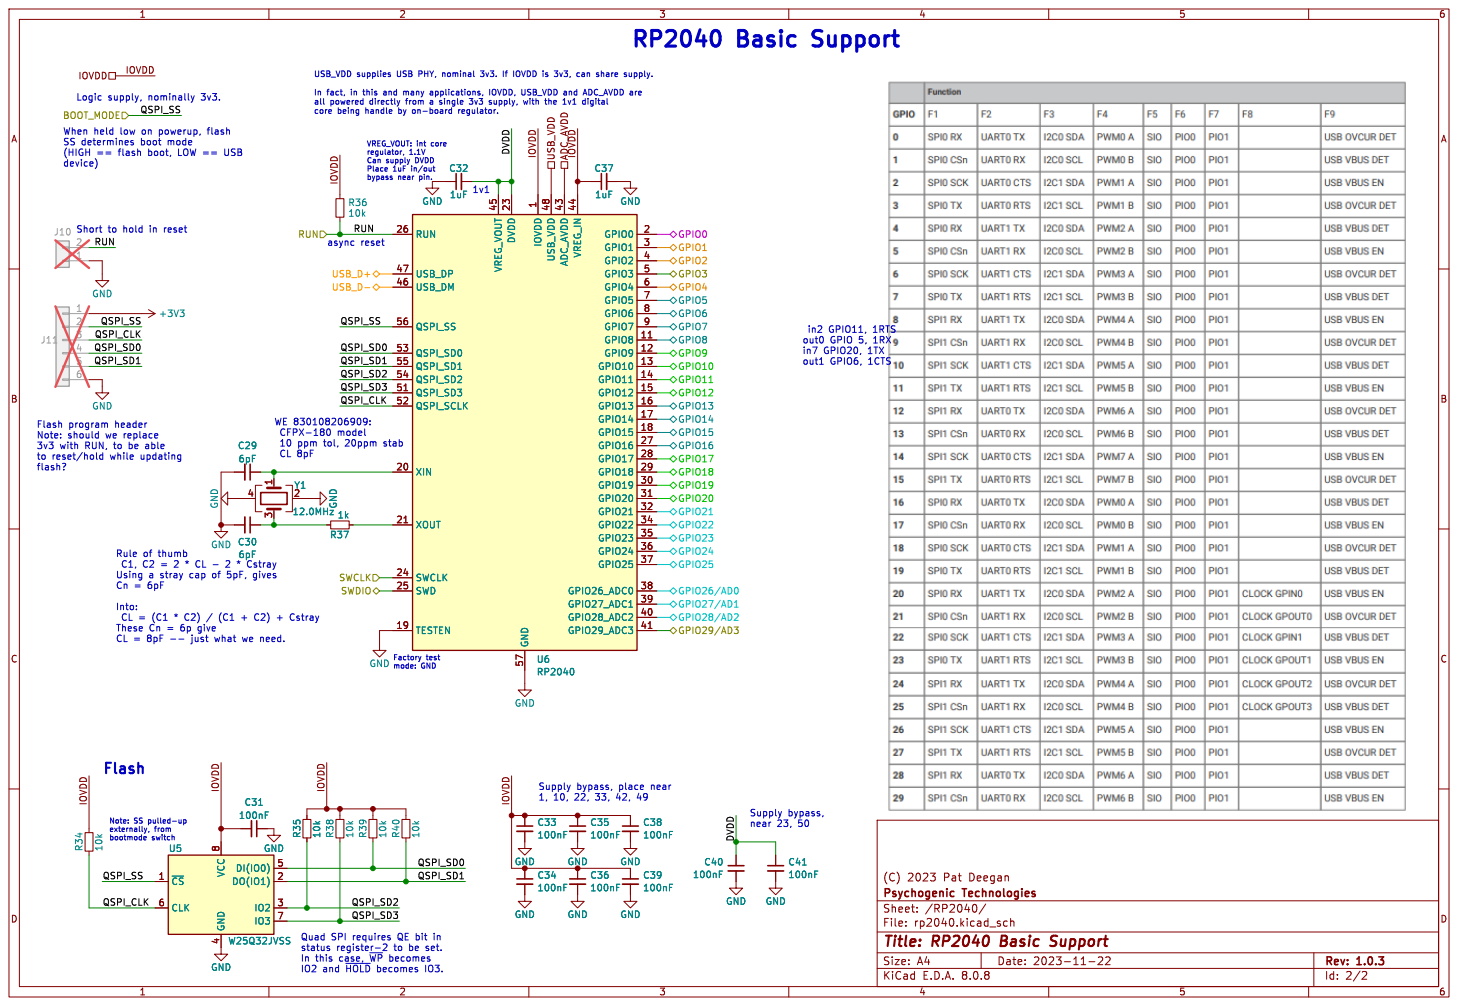
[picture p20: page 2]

(HIGH == flash boot, LOW == USB
1v1 Flash

1 GPIO8 11 GPIO9 12 GPIO10 13 GPIO11 14 GPIO12 15 GPIO13 16 GPIO14 17 GPIO15 18 TESTEN 19 GPIO0 2 XIN 20 XOUT 21 DVDD 23 SWCLK 24 SWD 25 RUN 26 GPIO16 27 GPIO17 28 GPIO18 29 GPIO1 3 GPIO19 30 GPIO20 31 GPIO21 32 GPIO22 34 GPIO23 35 GPIO24 36 GPIO25 37 GPIO26_ADC0 38 GPIO27_ADC1 39 GPIO2 4 GPIO28_ADC2 40 GPIO29_ADC3 41 ADC_AVDD 43 VREG_IN 44 VREG_VOUT 45 USB_DM 46 USB_DP 47 USB_VDD 48 GPIO3 5 QSPI_SD3 51 QSPI_SCLK 52 QSPI_SD0 53 QSPI_SD2 54 QSPI_SD1 55 QSPI_SS 56 GND 57 GPIO4 6 GPIO5 7 GPIO6 8 GPIO7 9 GND

1 GPIO8 11 GPIO9 12 GPIO10 13 GPIO11 14 GPIO12 15 GPIO13 16 GPIO14 17 GPIO15 18 TESTEN 19 GPIO0 2 XIN 20 XOUT 21 DVDD 23 SWCLK 24 SWD 25 RUN 26 GPIO16 27 GPIO17 28 GPIO18 29 GPIO1 3 GPIO19 30 GPIO20 31 GPIO21 32 GPIO22 34 GPIO23 35 GPIO24 36 GPIO25 37 GPIO26_ADC0 38 GPIO27_ADC1 39 GPIO2 4 GPIO28_ADC2 40 GPIO29_ADC3 41 ADC_AVDD 43 VREG_IN 44 VREG_VOUT 45 USB_DM 46 USB_DP 47 USB_VDD 48 GPIO3 5 QSPI_SD3 51 QSPI_SCLK 52 QSPI_SD0 53 QSPI_SD2 54 QSPI_SD1 55 QSPI_SS 56 GND 57 GPIO4 6 GPIO5 7 GPIO6 8 GPIO7 9 U6 RP2040

Factory test mode: GND Flash program header Note: should we replace

3v3 with RUN, to be able
flash?

Rule of thumb C1, C2 = 2 * CL - 2 * Cstray

Using a stray cap of 5pF, gives Cn = 6pF

Supply bypass, near 23, 50 Quad SPI requires QE bit in

Note: SS pulled-up

In this case, ~{WP}becomes

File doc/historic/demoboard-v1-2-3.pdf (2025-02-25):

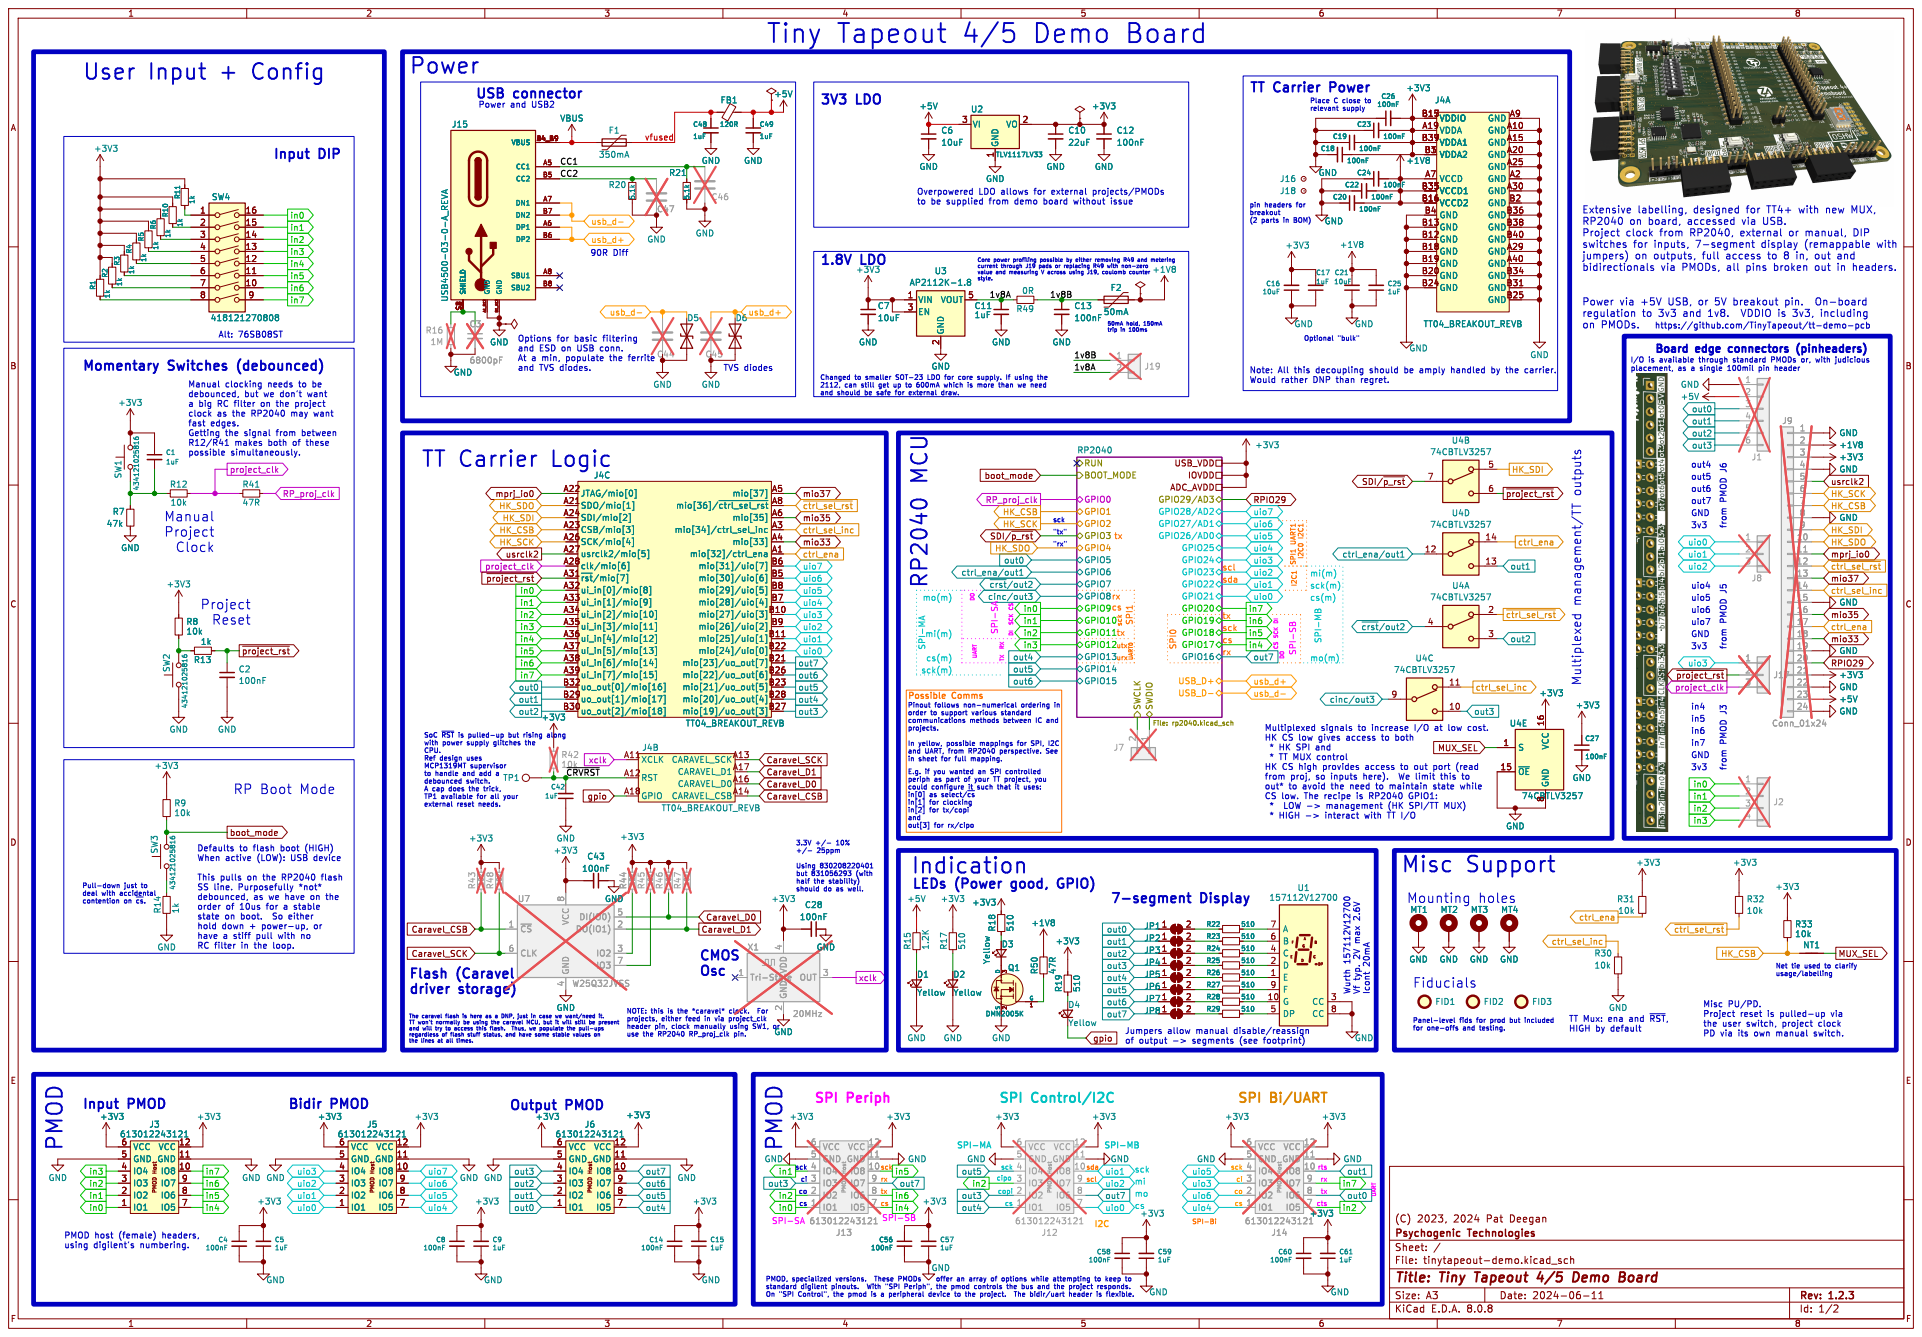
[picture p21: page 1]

in sheet for full mapping. RP2040 MCU

trip in 100ms Possible Comms

Options for basic filtering

2112, can still get up to 600mA which is more than we need

JTAG/mio[0] A22 CSB/mio[3] A23 SDI/mio[2] A24 SCK/mio[4] A26

TT Mux: ena and ~{RST}, HIGH by default SPI1

E.g. if you wanted an SPI controlled
Indication

* HK SPI and
* TT MUX control HK CS high provides access to out port (read

the user switch, project clock PD via its own manual switch. Net tie used to clarify usage/labelling Misc Support

order of 10us for a stable

out7
Jumpers allow manual disable/reassign

cs SPI-SA PMOD Standard Pinouts

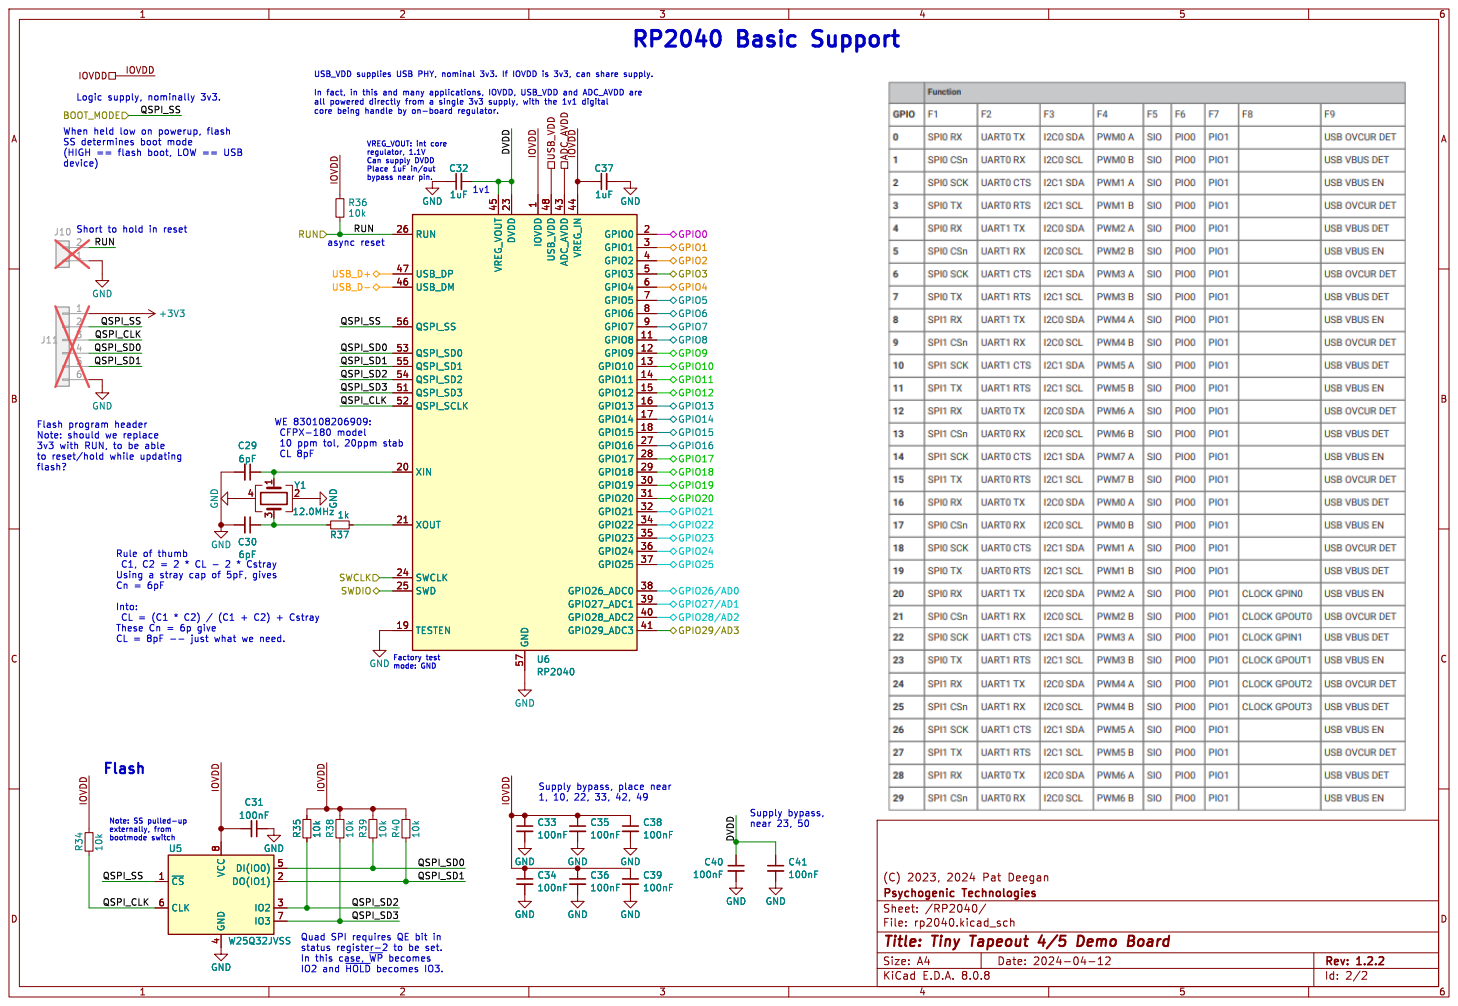
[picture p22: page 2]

async reset Quad SPI requires QE bit in

(HIGH == flash boot, LOW == USB
device)

1v1 Rule of thumb C1, C2 = 2 * CL - 2 * Cstray

1 GPIO8 11 GPIO9 12 GPIO10 13 GPIO11 14 GPIO12 15 GPIO13 16 GPIO14 17 GPIO15 18 TESTEN 19 GPIO0 2 XIN 20 XOUT 21 DVDD 23 SWCLK 24 SWD 25 RUN 26 GPIO16 27 GPIO17 28 GPIO18 29 GPIO1 3 GPIO19 30 GPIO20 31 GPIO21 32 GPIO22 34 GPIO23 35 GPIO24 36 GPIO25 37 GPIO26_ADC0 38 GPIO27_ADC1 39 GPIO2 4 GPIO28_ADC2 40 GPIO29_ADC3 41 ADC_AVDD 43 VREG_IN 44 VREG_VOUT 45 USB_DM 46 USB_DP 47 USB_VDD 48 GPIO3 5 QSPI_SD3 51 QSPI_SCLK 52 QSPI_SD0 53 QSPI_SD2 54 QSPI_SD1 55 QSPI_SS 56 GND 57 GPIO4 6 GPIO5 7 GPIO6 8 GPIO7 9 GND

1 GPIO8 11 GPIO9 12 GPIO10 13 GPIO11 14 GPIO12 15 GPIO13 16 GPIO14 17 GPIO15 18 TESTEN 19 GPIO0 2 XIN 20 XOUT 21 DVDD 23 SWCLK 24 SWD 25 RUN 26 GPIO16 27 GPIO17 28 GPIO18 29 GPIO1 3 GPIO19 30 GPIO20 31 GPIO21 32 GPIO22 34 GPIO23 35 GPIO24 36 GPIO25 37 GPIO26_ADC0 38 GPIO27_ADC1 39 GPIO2 4 GPIO28_ADC2 40 GPIO29_ADC3 41 ADC_AVDD 43 VREG_IN 44 VREG_VOUT 45 USB_DM 46 USB_DP 47 USB_VDD 48 GPIO3 5 QSPI_SD3 51 QSPI_SCLK 52 QSPI_SD0 53 QSPI_SD2 54 QSPI_SD1 55 QSPI_SS 56 GND 57 GPIO4 6 GPIO5 7 GPIO6 8 GPIO7 9 U6 RP2040

Flash program header Note: should we replace

3v3 with RUN, to be able
flash?

Using a stray cap of 5pF, gives Cn = 6pF

Factory test mode: GND

Note: SS pulled-up

In this case, ~{WP}becomes
IO2 and ~{HOLD}becomes IO3.

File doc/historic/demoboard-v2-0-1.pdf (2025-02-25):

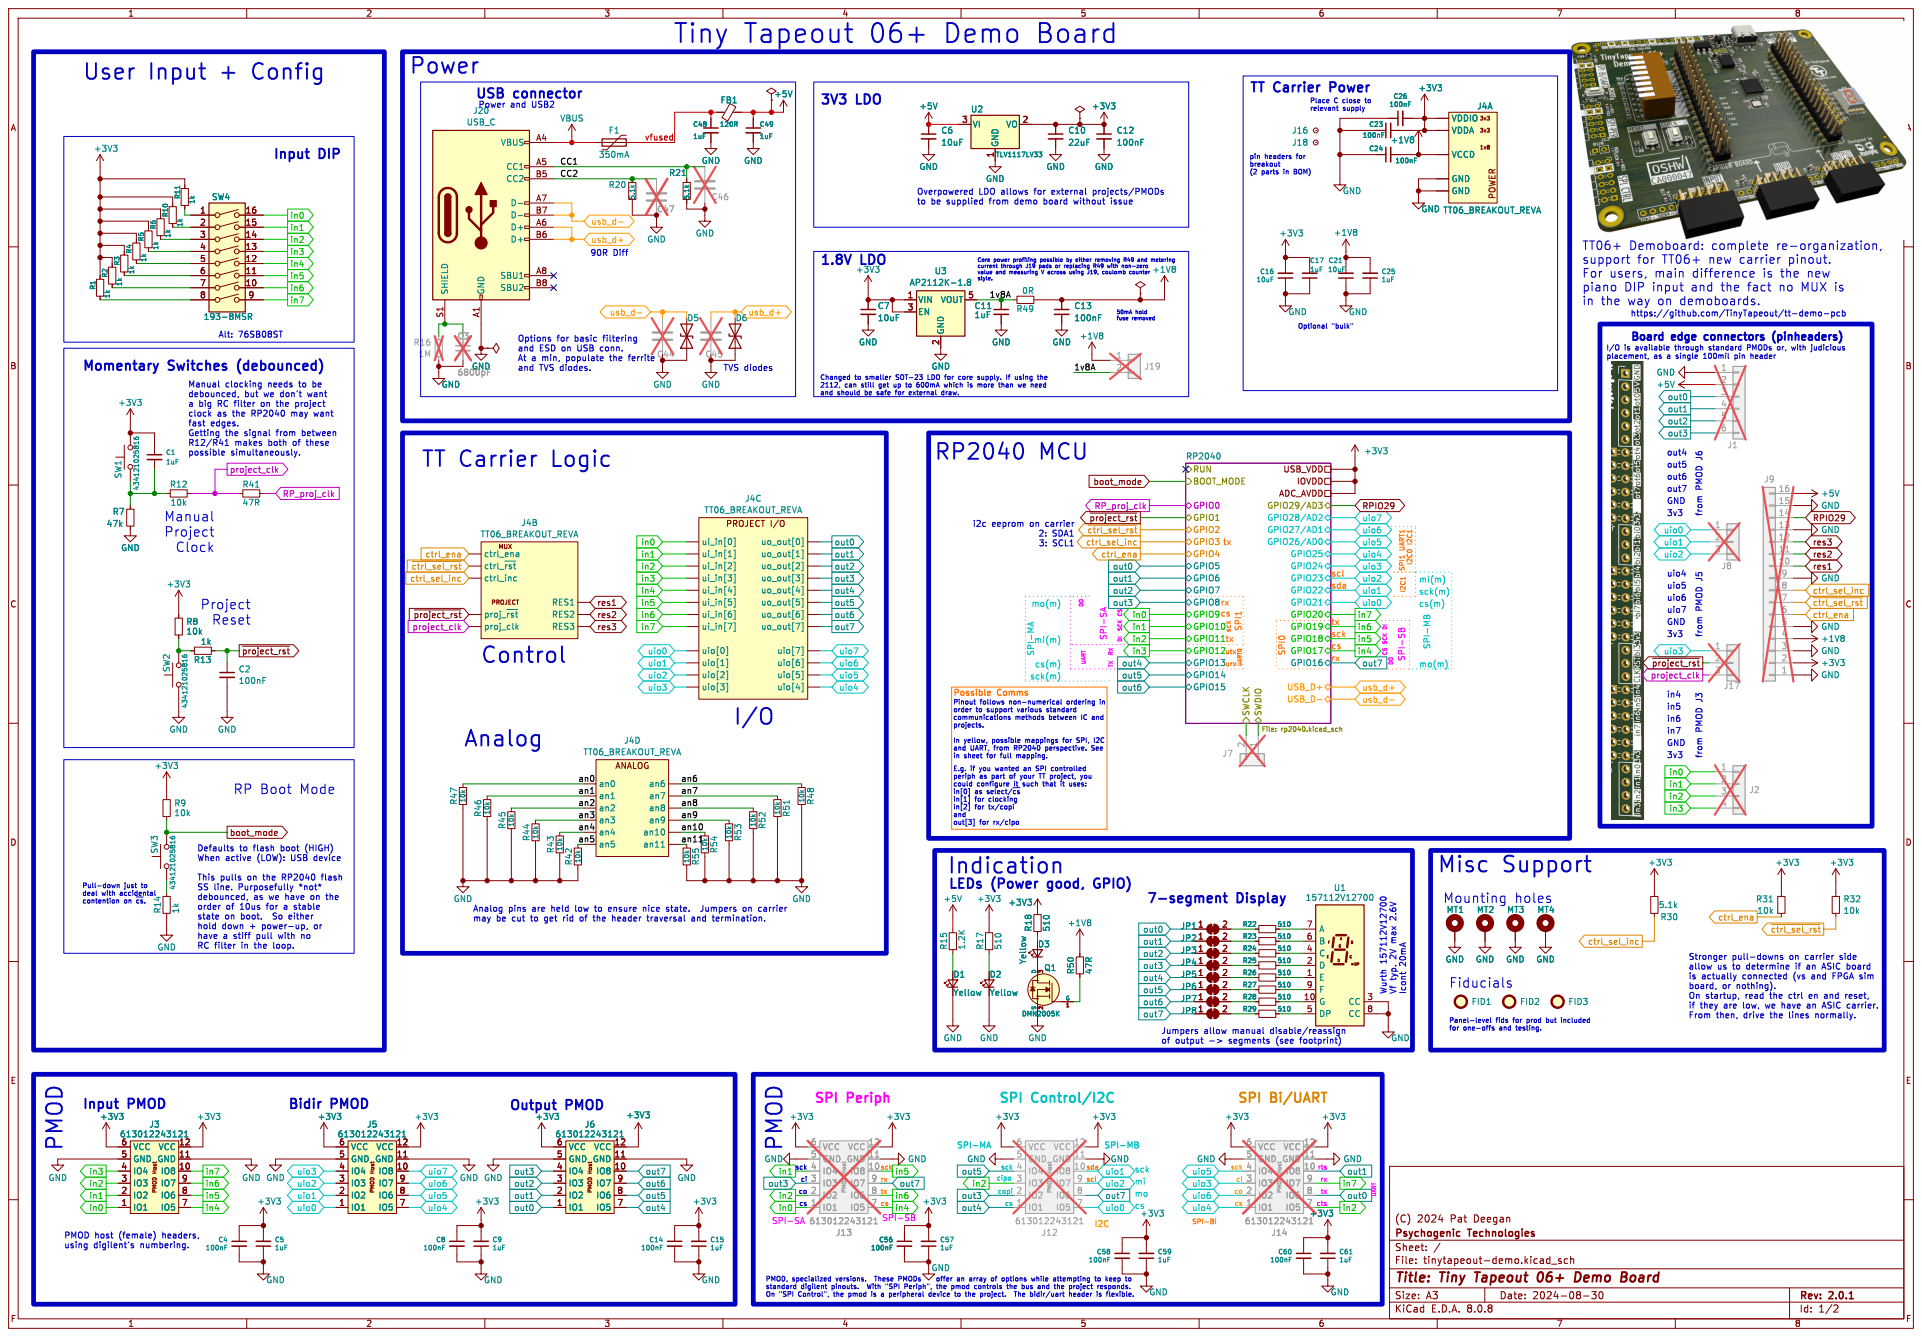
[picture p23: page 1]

User Input + Config PMOD

Tiny Tapeout 06+ Demo Board

2 EN 3 VOUT 5 U3 AP2112K-1.8 GND 10k R54R44 10k 10k R53 R42 10kR43 10k GND

support for TT06+ new carrier pinout.
piano DIP input and the fact no MUX is
in the way on demoboards.

https://github.com/TinyTapeout/tt-demo-pcb
J17 GND
out0

Options for basic filtering

2112, can still get up to 600mA which is more than we need

in sheet for full mapping. Possible Comms
in6 SPI Control/I2C

E.g. if you wanted an SPI controlled

order of 10us for a stable

if they are low, we have an ASIC carrier. From then, drive the lines normally.

Id: 1/2 Title: Tiny Tapeout 06+ Demo Board

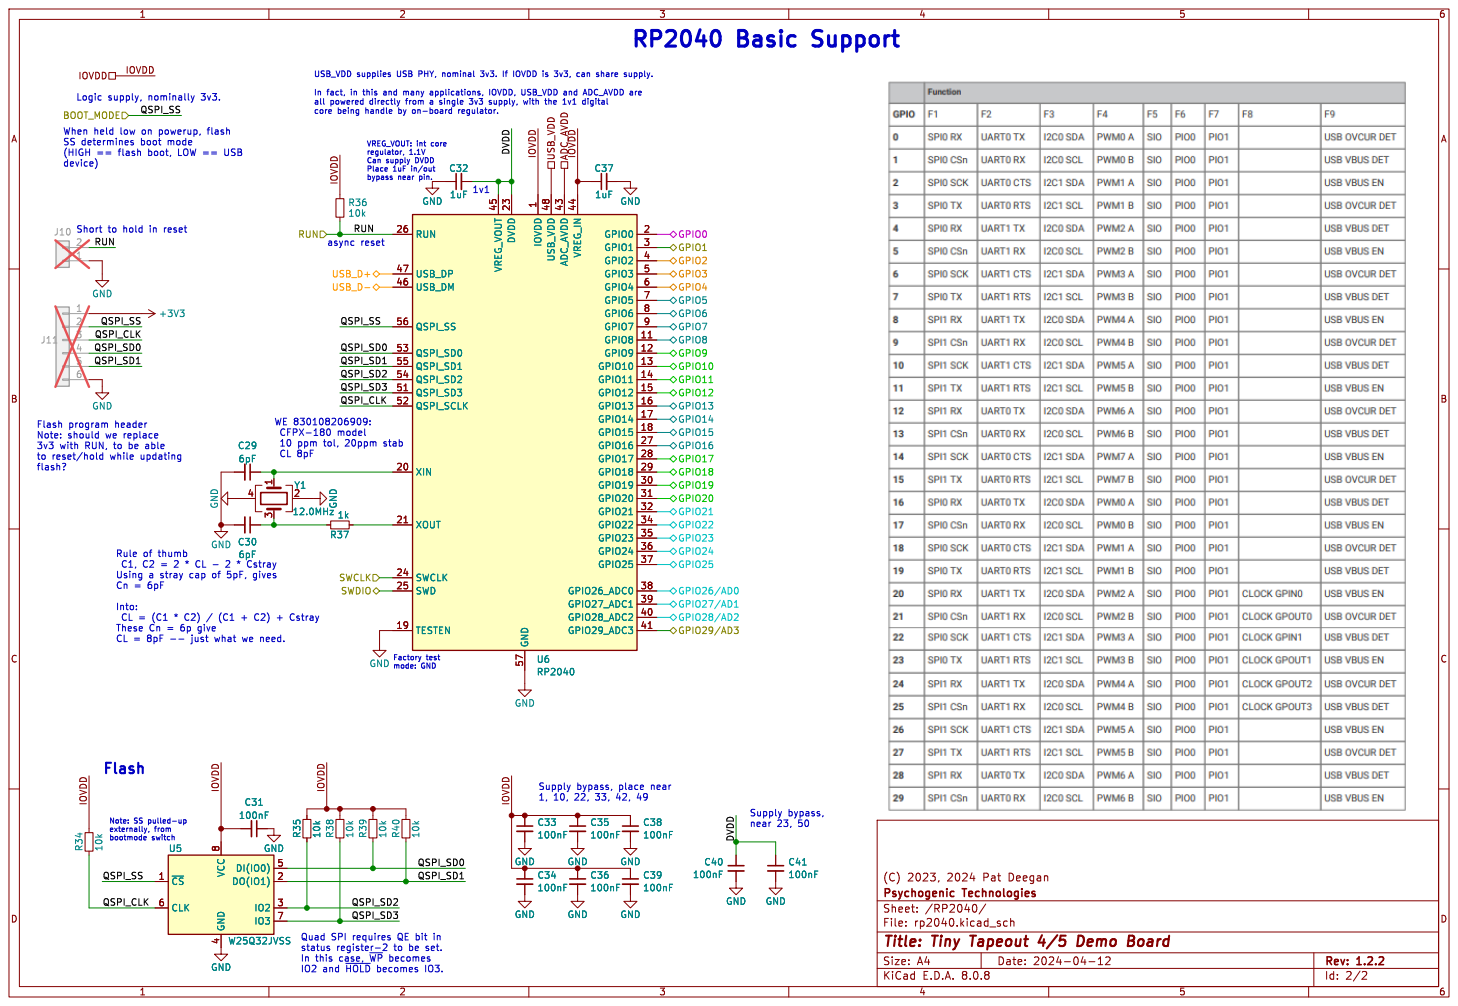
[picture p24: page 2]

async reset Quad SPI requires QE bit in

(HIGH == flash boot, LOW == USB
device)

1v1 Rule of thumb C1, C2 = 2 * CL - 2 * Cstray

1 GPIO8 11 GPIO9 12 GPIO10 13 GPIO11 14 GPIO12 15 GPIO13 16 GPIO14 17 GPIO15 18 TESTEN 19 GPIO0 2 XIN 20 XOUT 21 DVDD 23 SWCLK 24 SWD 25 RUN 26 GPIO16 27 GPIO17 28 GPIO18 29 GPIO1 3 GPIO19 30 GPIO20 31 GPIO21 32 GPIO22 34 GPIO23 35 GPIO24 36 GPIO25 37 GPIO26_ADC0 38 GPIO27_ADC1 39 GPIO2 4 GPIO28_ADC2 40 GPIO29_ADC3 41 ADC_AVDD 43 VREG_IN 44 VREG_VOUT 45 USB_DM 46 USB_DP 47 USB_VDD 48 GPIO3 5 QSPI_SD3 51 QSPI_SCLK 52 QSPI_SD0 53 QSPI_SD2 54 QSPI_SD1 55 QSPI_SS 56 GND 57 GPIO4 6 GPIO5 7 GPIO6 8 GPIO7 9 GND

1 GPIO8 11 GPIO9 12 GPIO10 13 GPIO11 14 GPIO12 15 GPIO13 16 GPIO14 17 GPIO15 18 TESTEN 19 GPIO0 2 XIN 20 XOUT 21 DVDD 23 SWCLK 24 SWD 25 RUN 26 GPIO16 27 GPIO17 28 GPIO18 29 GPIO1 3 GPIO19 30 GPIO20 31 GPIO21 32 GPIO22 34 GPIO23 35 GPIO24 36 GPIO25 37 GPIO26_ADC0 38 GPIO27_ADC1 39 GPIO2 4 GPIO28_ADC2 40 GPIO29_ADC3 41 ADC_AVDD 43 VREG_IN 44 VREG_VOUT 45 USB_DM 46 USB_DP 47 USB_VDD 48 GPIO3 5 QSPI_SD3 51 QSPI_SCLK 52 QSPI_SD0 53 QSPI_SD2 54 QSPI_SD1 55 QSPI_SS 56 GND 57 GPIO4 6 GPIO5 7 GPIO6 8 GPIO7 9 U6 RP2040

Flash program header Note: should we replace

3v3 with RUN, to be able
flash?

Using a stray cap of 5pF, gives Cn = 6pF

Factory test mode: GND

Note: SS pulled-up

In this case, ~{WP}becomes
IO2 and ~{HOLD}becomes IO3.

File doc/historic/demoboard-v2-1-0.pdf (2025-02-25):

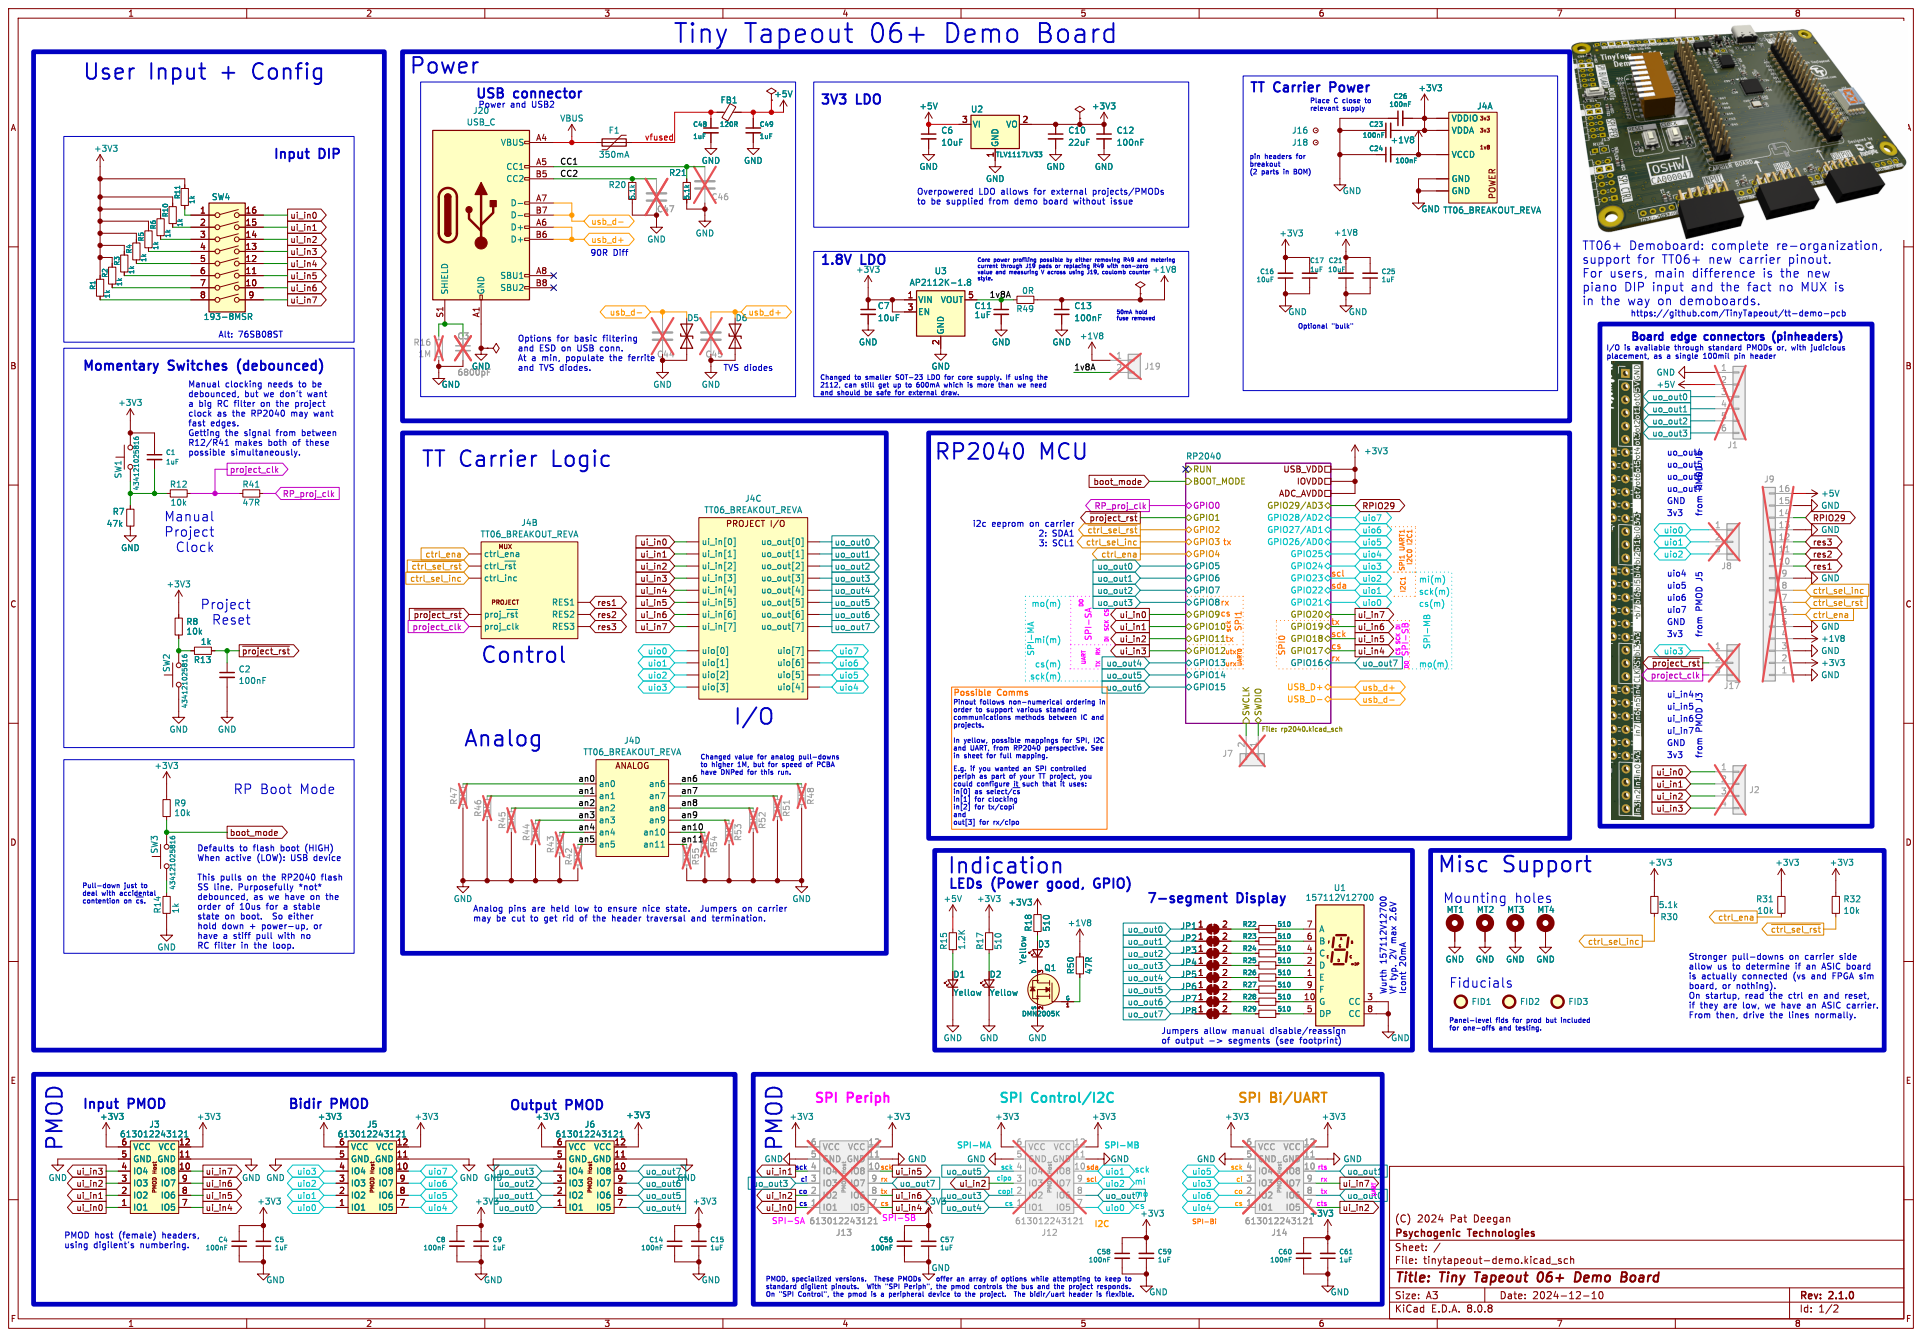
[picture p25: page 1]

pin headers for breakout (2 parts in BOM) 3V3 LDO

support for TT06+ new carrier pinout.
piano DIP input and the fact no MUX is
in the way on demoboards.

https://github.com/TinyTapeout/tt-demo-pcb
~{project_rst} uo_out3
uo_out4

Alt: 76SB08ST Momentary Switches (debounced)

uo_out7 Options for basic filtering

2112, can still get up to 600mA which is more than we need

in sheet for full mapping.
E.g. if you wanted an SPI controlled

Changed value for analog pull-downs
to higher 1M, but for speed of PCBA

order of 10us for a stable

if they are low, we have an ASIC carrier. From then, drive the lines normally. cts

Jumpers allow manual disable/reassign

Id: 1/2 Title: Tiny Tapeout 06+ Demo Board

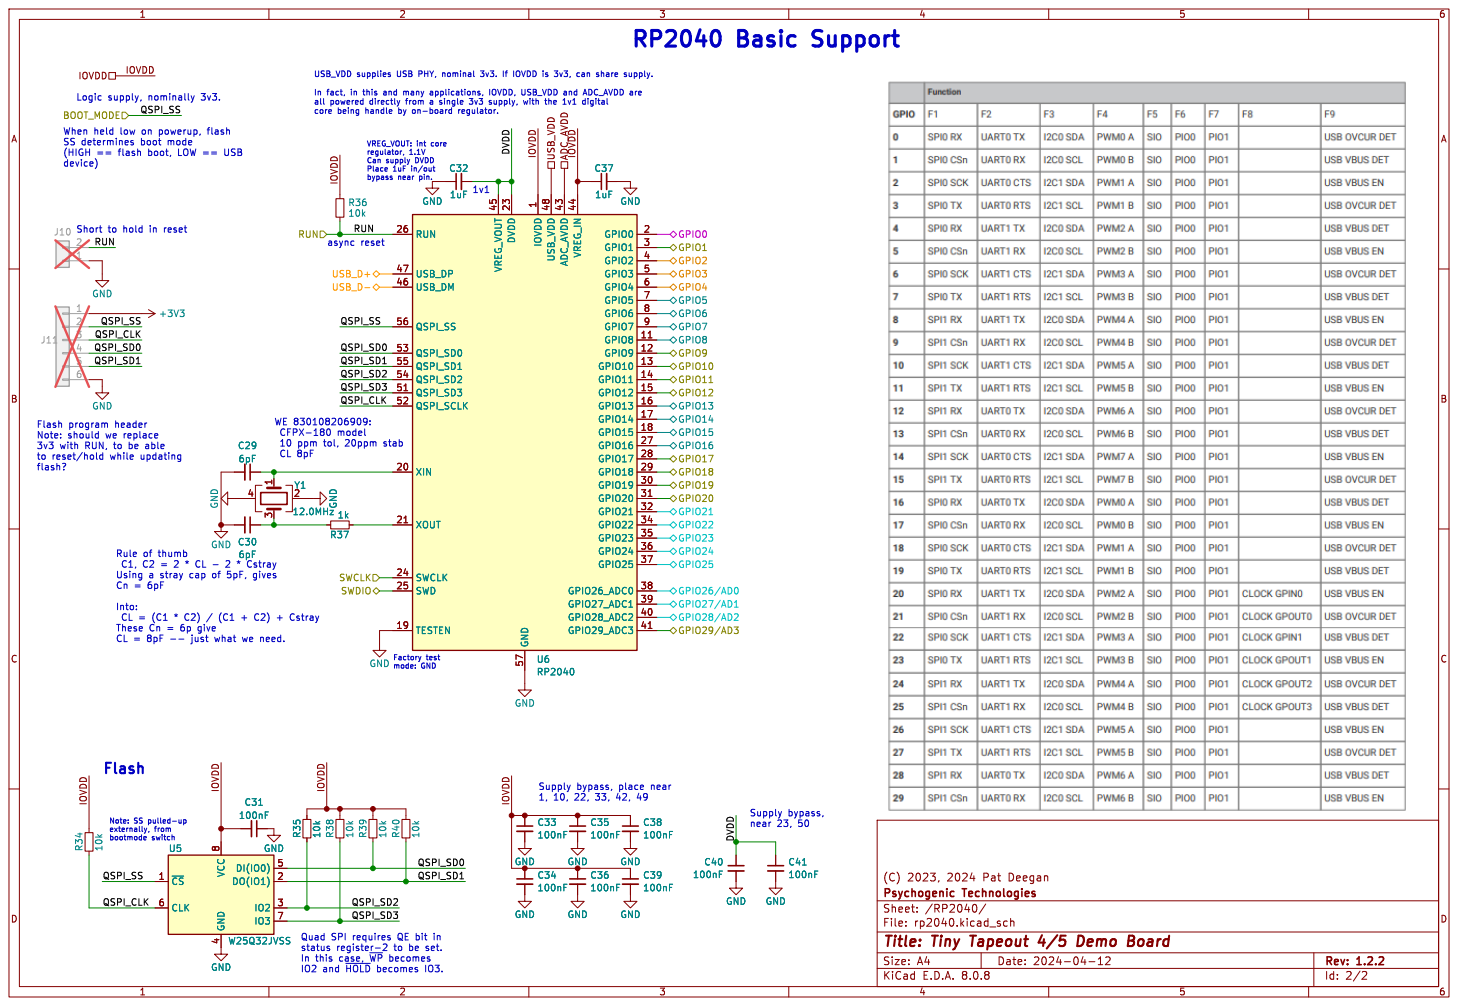
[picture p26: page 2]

async reset Quad SPI requires QE bit in

(HIGH == flash boot, LOW == USB
device)

1v1 Rule of thumb C1, C2 = 2 * CL - 2 * Cstray

1 GPIO8 11 GPIO9 12 GPIO10 13 GPIO11 14 GPIO12 15 GPIO13 16 GPIO14 17 GPIO15 18 TESTEN 19 GPIO0 2 XIN 20 XOUT 21 DVDD 23 SWCLK 24 SWD 25 RUN 26 GPIO16 27 GPIO17 28 GPIO18 29 GPIO1 3 GPIO19 30 GPIO20 31 GPIO21 32 GPIO22 34 GPIO23 35 GPIO24 36 GPIO25 37 GPIO26_ADC0 38 GPIO27_ADC1 39 GPIO2 4 GPIO28_ADC2 40 GPIO29_ADC3 41 ADC_AVDD 43 VREG_IN 44 VREG_VOUT 45 USB_DM 46 USB_DP 47 USB_VDD 48 GPIO3 5 QSPI_SD3 51 QSPI_SCLK 52 QSPI_SD0 53 QSPI_SD2 54 QSPI_SD1 55 QSPI_SS 56 GND 57 GPIO4 6 GPIO5 7 GPIO6 8 GPIO7 9 GND

1 GPIO8 11 GPIO9 12 GPIO10 13 GPIO11 14 GPIO12 15 GPIO13 16 GPIO14 17 GPIO15 18 TESTEN 19 GPIO0 2 XIN 20 XOUT 21 DVDD 23 SWCLK 24 SWD 25 RUN 26 GPIO16 27 GPIO17 28 GPIO18 29 GPIO1 3 GPIO19 30 GPIO20 31 GPIO21 32 GPIO22 34 GPIO23 35 GPIO24 36 GPIO25 37 GPIO26_ADC0 38 GPIO27_ADC1 39 GPIO2 4 GPIO28_ADC2 40 GPIO29_ADC3 41 ADC_AVDD 43 VREG_IN 44 VREG_VOUT 45 USB_DM 46 USB_DP 47 USB_VDD 48 GPIO3 5 QSPI_SD3 51 QSPI_SCLK 52 QSPI_SD0 53 QSPI_SD2 54 QSPI_SD1 55 QSPI_SS 56 GND 57 GPIO4 6 GPIO5 7 GPIO6 8 GPIO7 9 U6 RP2040

Flash program header Note: should we replace

3v3 with RUN, to be able
flash?

Using a stray cap of 5pF, gives Cn = 6pF

Factory test mode: GND

Note: SS pulled-up

In this case, ~{WP}becomes
IO2 and ~{HOLD}becomes IO3.

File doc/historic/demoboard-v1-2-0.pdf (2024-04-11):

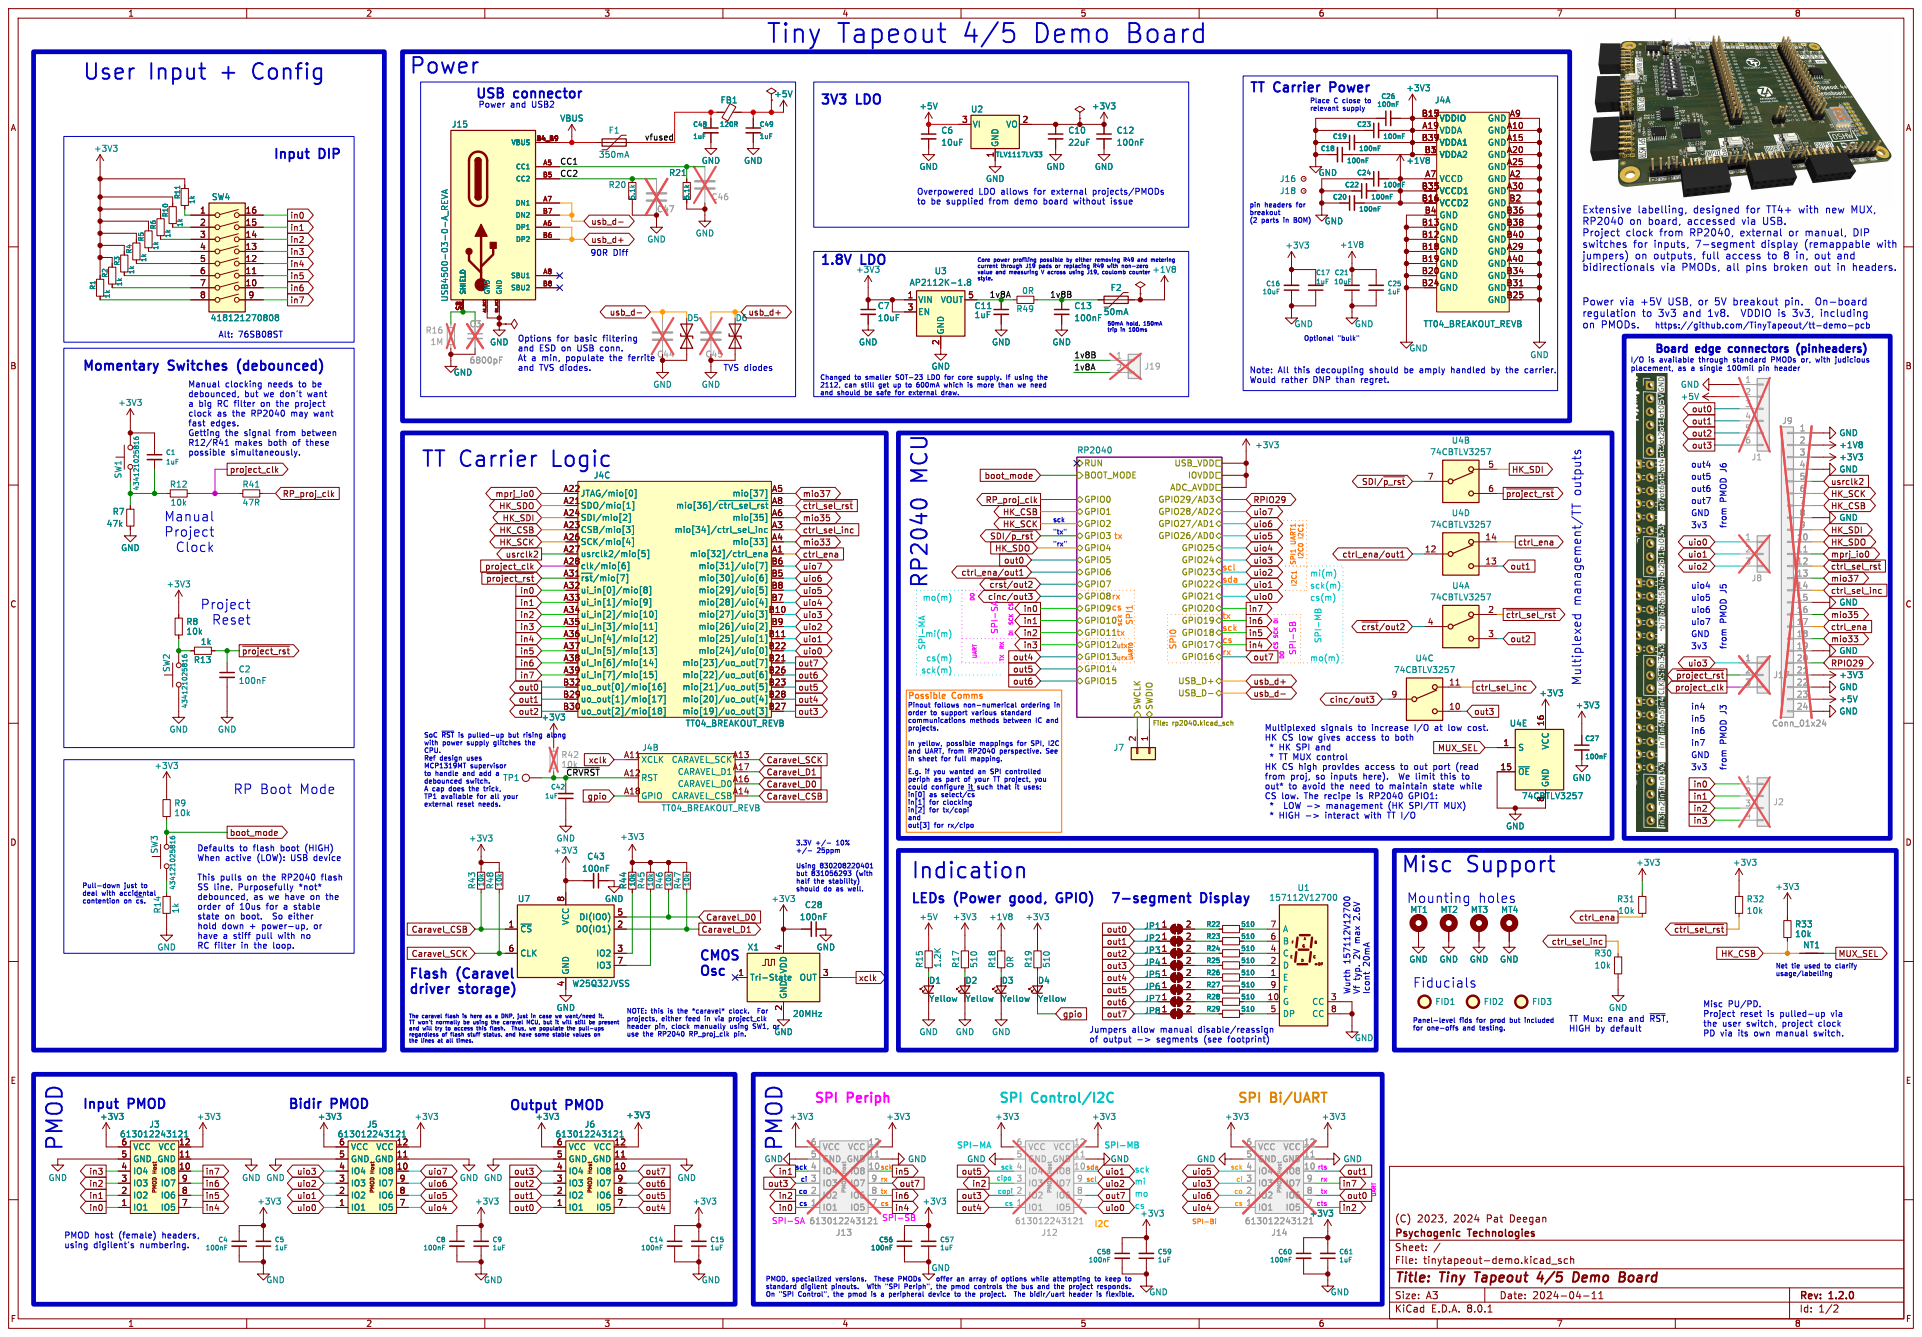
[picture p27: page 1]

trip in 100ms Tiny Tapeout 4/5 Demo Board

Options for basic filtering

2112, can still get up to 600mA which is more than we need

JTAG/mio[0] A22 CSB/mio[3] A23 SDI/mio[2] A24 SCK/mio[4] A26

TT Mux: ena and ~{RST}, HIGH by default mo(m)

~{crst}/out2
cinc/out3
Net tie used to clarify usage/labelling DO

in sheet for full mapping.
E.g. if you wanted an SPI controlled

* HK SPI and
* TT MUX control HK CS high provides access to out port (read

to handle and add a

order of 10us for a stable

the user switch, project clock PD via its own manual switch.


(HIGH == flash boot, LOW == USB
1v1 Flash

1 GPIO8 11 GPIO9 12 GPIO10 13 GPIO11 14 GPIO12 15 GPIO13 16 GPIO14 17 GPIO15 18 TESTEN 19 GPIO0 2 XIN 20 XOUT 21 DVDD 23 SWCLK 24 SWD 25 RUN 26 GPIO16 27 GPIO17 28 GPIO18 29 GPIO1 3 GPIO19 30 GPIO20 31 GPIO21 32 GPIO22 34 GPIO23 35 GPIO24 36 GPIO25 37 GPIO26_ADC0 38 GPIO27_ADC1 39 GPIO2 4 GPIO28_ADC2 40 GPIO29_ADC3 41 ADC_AVDD 43 VREG_IN 44 VREG_VOUT 45 USB_DM 46 USB_DP 47 USB_VDD 48 GPIO3 5 QSPI_SD3 51 QSPI_SCLK 52 QSPI_SD0 53 QSPI_SD2 54 QSPI_SD1 55 QSPI_SS 56 GND 57 GPIO4 6 GPIO5 7 GPIO6 8 GPIO7 9 GND

1 GPIO8 11 GPIO9 12 GPIO10 13 GPIO11 14 GPIO12 15 GPIO13 16 GPIO14 17 GPIO15 18 TESTEN 19 GPIO0 2 XIN 20 XOUT 21 DVDD 23 SWCLK 24 SWD 25 RUN 26 GPIO16 27 GPIO17 28 GPIO18 29 GPIO1 3 GPIO19 30 GPIO20 31 GPIO21 32 GPIO22 34 GPIO23 35 GPIO24 36 GPIO25 37 GPIO26_ADC0 38 GPIO27_ADC1 39 GPIO2 4 GPIO28_ADC2 40 GPIO29_ADC3 41 ADC_AVDD 43 VREG_IN 44 VREG_VOUT 45 USB_DM 46 USB_DP 47 USB_VDD 48 GPIO3 5 QSPI_SD3 51 QSPI_SCLK 52 QSPI_SD0 53 QSPI_SD2 54 QSPI_SD1 55 QSPI_SS 56 GND 57 GPIO4 6 GPIO5 7 GPIO6 8 GPIO7 9 U6 RP2040

Factory test mode: GND Flash program header Note: should we replace

3v3 with RUN, to be able
flash?

Rule of thumb C1, C2 = 2 * CL - 2 * Cstray

Using a stray cap of 5pF, gives Cn = 6pF

Supply bypass, near 23, 50 Quad SPI requires QE bit in

Note: SS pulled-up

In this case, ~{WP}becomes

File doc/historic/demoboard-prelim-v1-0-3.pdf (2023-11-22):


TinyTapeout 4/5 Demo Board (preliminary)

GND GND GND GND GND

2112, can still get up to 600mA which is more than we need

the user switch, project clock PD via its own manual switch. SPI1 UART1 I2C0 I2C1

projects.
in7 LEDs (Power good, GPIO)
E.g. if you wanted an SPI controlled

* HK SPI and
* TT MUX control HK CS high provides access to out port (read

to handle and add a

order of 10us for a stable


(HIGH == flash boot, LOW == USB

Place 1uF in/out bypass near pin.

async reset Flash program header Note: should we replace
IO2 and ~{HOLD}becomes IO3. GNDY1
1k GND
6pFC31

1 GPIO8 11 GPIO9 12 GPIO10 13 GPIO11 14 GPIO12 15 GPIO13 16 GPIO14 17 GPIO15 18 TESTEN 19 GPIO0 2 XIN 20 XOUT 21 DVDD 23 SWCLK 24 SWD 25 RUN 26 GPIO16 27 GPIO17 28 GPIO18 29 GPIO1 3 GPIO19 30 GPIO20 31 GPIO21 32 GPIO22 34 GPIO23 35 GPIO24 36 GPIO25 37 GPIO26_ADC0 38 GPIO27_ADC1 39 GPIO2 4 GPIO28_ADC2 40 GPIO29_ADC3 41 ADC_AVDD 43 VREG_IN 44 VREG_VOUT 45 USB_DM 46 USB_DP 47 USB_VDD 48 GPIO3 5 QSPI_SD3 51 QSPI_SCLK 52 QSPI_SD0 53 QSPI_SD2 54 QSPI_SD1 55 QSPI_SS 56 GND 57 GPIO4 6 GPIO5 7 GPIO6 8 GPIO7 9 U6 RP2040 GND

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

3v3 with RUN, to be able

Using a stray cap of 5pF, gives Cn = 6pF

Factory test mode: GND

Note: SS pulled-up

In this case, ~{WP}becomes



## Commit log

2023-10-13 docs: update RP2040 pinout to match schematic
2023-10-13 Additional pin function options
2023-10-14 Preliminary schematic for TT4+ demo boards
    [rp2040.kicad_sch, tinytapeout-demo.kicad_pcb, tinytapeout-demo.kicad_sch]
2023-10-14 deprecated layout
    [tinytapeout-demo.kicad_pcb]
2023-10-27 docs(README): fix I2C pinout
2023-11-19 TT 4+ pre-route alpha schem and layout reset
    [rp2040.kicad_sch, tinytapeout-demo.kicad_pcb, tinytapeout-demo.kicad_sch]
2023-11-20 reassignments, new dual-purpose pmod/iohead, floorplan
    [rp2040.kicad_sch, tinytapeout-demo.kicad_pcb, tinytapeout-demo.kicad_sch]
2023-11-22 v1.0.3 alpha: out to fab
    [rp2040.kicad_sch, tinytapeout-demo.kicad_sch]
2023-12-14 TT04 new breakout pre-rework
    [rp2040.kicad_sch, tinytapeout-demo.kicad_sch]
2023-12-14 carrier traces wiped
    [tinytapeout-demo.kicad_sch]
2023-12-15 schem v1.0.4 (routing 0.9.4) alpha--TT04+ v3 carrier breakout mapping
    [tinytapeout-demo.kicad_sch]
2024-01-14 v1.0.4 alpha as assembled for test run
    [rp2040.kicad_sch, tinytapeout-demo.kicad_sch]
2024-01-31 v1.0.5, post alpha pcba modifications
    [tinytapeout-demo.kicad_sch]
2024-01-31 minor cleanup/comments
    [tinytapeout-demo.kicad_sch]
2024-03-01 remap out0/out1 and MUX, routing, silk rework
    [tinytapeout-demo.kicad_sch]
2024-03-01 reworked UART pmod, 1v8 fused and instrumentable
    [rp2040.kicad_sch, tinytapeout-demo.kicad_sch]
2024-03-01 v1.1.0 with docs
    [tinytapeout-demo.kicad_sch]
2024-03-01 KiCad 8 migration
    [rp2040.kicad_sch, tinytapeout-demo.kicad_sch]
2024-03-12 v3p5 pcba BOM tweaks
    [rp2040.kicad_sch, tinytapeout-demo.kicad_sch]
2024-03-12 v1.1.1 compliance with newspeak is double-plus-good
    [tinytapeout-demo.kicad_sch]
2024-03-12 v1.1.1 docs
    [tinytapeout-demo.kicad_sch]
2024-04-11 JLC MPNs
    [rp2040.kicad_sch]
2024-04-11 JLC MPNs, mux ctrl ena pullup fix
    [tinytapeout-demo.kicad_sch]
2024-04-11 ctrl ena pullup, 5V sliver fixes
2024-04-11 PMOD header DNP swap/fix
    [rp2040.kicad_sch, tinytapeout-demo.kicad_sch]
2024-04-11 UART pmod fix, minor routing and silk cleanups
    [tinytapeout-demo.kicad_sch]
2024-04-12 Uniformized 0R to use 0603, PMOD DNPs v1.2.1
    [tinytapeout-demo.kicad_sch]
2024-04-27 Modified silk and BOM for TT04 run
    [tinytapeout-demo.kicad_sch]
2024-06-11 v1.2.3, TT05 run plus mod to brighten 1v8 LED (pwr via 3v3, gate fet using 1v8)
    [rp2040.kicad_sch, tinytapeout-demo.kicad_sch]
2024-07-15 add note on extraction of pcb
    [pcb_extractor.stl]
2024-08-07 minor tweaks, pre tt06 prep
    [tinytapeout-demo.kicad_sch]
2024-08-12 Added .STEP file for the PCB
2024-08-12 Added .STL file for the PCB
2025-02-25 tt kicad libs refresh
2025-02-25 TT06 prelim alpha1 schem
    [tinytapeout-demo.kicad_sch]
2025-02-25 first remap of pcb and global delete of all routing
    [tinytapeout-demo.kicad_sch]
2025-02-25 v2.0.0 alpha, as produced for prototype run
    [rp2040.kicad_sch, tinytapeout-demo.kicad_pcb, tinytapeout-demo.kicad_sch]
2025-02-25 minor fab cleanups
    [tinytapeout-demo.kicad_pcb, tinytapeout-demo.kicad_sch]
2025-02-25 renamed JLC field to LCSC, minor tweaks to BOM
    [rp2040.kicad_sch, tinytapeout-demo.kicad_pcb, tinytapeout-demo.kicad_sch]
2025-02-25 the great net rename
    [tinytapeout-demo.kicad_pcb, tinytapeout-demo.kicad_sch]
2025-02-25 the great relabelling
    [tinytapeout-demo.kicad_pcb]
2025-02-25 Analog pulldown value raised, DNPed for TT07 run.
    [tinytapeout-demo.kicad_sch]
2025-02-25 v2.1.0, TT07
    [tinytapeout-demo.kicad_pcb, tinytapeout-demo.kicad_sch]
2025-02-25 efabless logo
    [tinytapeout-demo.kicad_pcb]
2025-02-25 Added skeleton case design
    [tt06_demo_base.scad, tt06_demo_base_m2_insert.stl, tt06_demo_base_m3_direct.stl]
2025-02-25 layout work to give space to lever out the breakout board
2025-02-25 re-populated the analog pull-downs
    [rp2040.kicad_sch, tinytapeout-demo.kicad_sch]
2025-02-25 schematic update
2025-02-25 Doc reorg and schematic/leaflet history
2025-02-25 Doc cleanup, got rid of reference to DB mux, notes on arrows for levering out breakout board
2026-06-23 Reworked manual clocking circuit, Iref current source for analog, TVS diodes on analog lines
    [rp2350.kicad_sch, tinytapeout-demo.kicad_pcb, tinytapeout-demo.kicad_sch]
2026-06-23 re-annotated entire schem
    [rp2350.kicad_sch, tinytapeout-demo.kicad_pcb, tinytapeout-demo.kicad_sch]
2026-06-23 minor pcb cleanup
    [tinytapeout-demo.kicad_pcb]
